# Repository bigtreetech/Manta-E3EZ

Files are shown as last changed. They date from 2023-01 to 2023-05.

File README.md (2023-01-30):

# Manta-E3EZ
## Note
With the Manta E3EZ board, we packed it with so many features and connectivity options that we needed to use M2 standoffs instead of M2.5 beneath the CB1 due to the track density. M2 screws will be included with most boards but if you do not receive M2 screws with your board then the specificatons for the correct screw are: M2x10, 4pcs.

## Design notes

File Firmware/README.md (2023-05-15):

# Writing bootloader for E3EZ
1. Download the [bootloader.bin](./E3EZ_bootloader.bin) file to CB1/CM4.
2. Press and hold the boot button of E3EZ and then click the reset button to make E3EZ goto DFU mode.
3. Run the following command on the Terminal of CB1/CM4 to write the bootloader
    ```
    sudo dfu-util -d ,0483:df11 -R -a 0 -s 0x8000000:leave -D ./E3EZ_bootloader.bin
    ```
    `0483:df11` is the DFU ID of M8P (We can get it by running `lsusb` command)</br>
    `./E3EZ_bootloader.bin` is the Path of bootloader file.

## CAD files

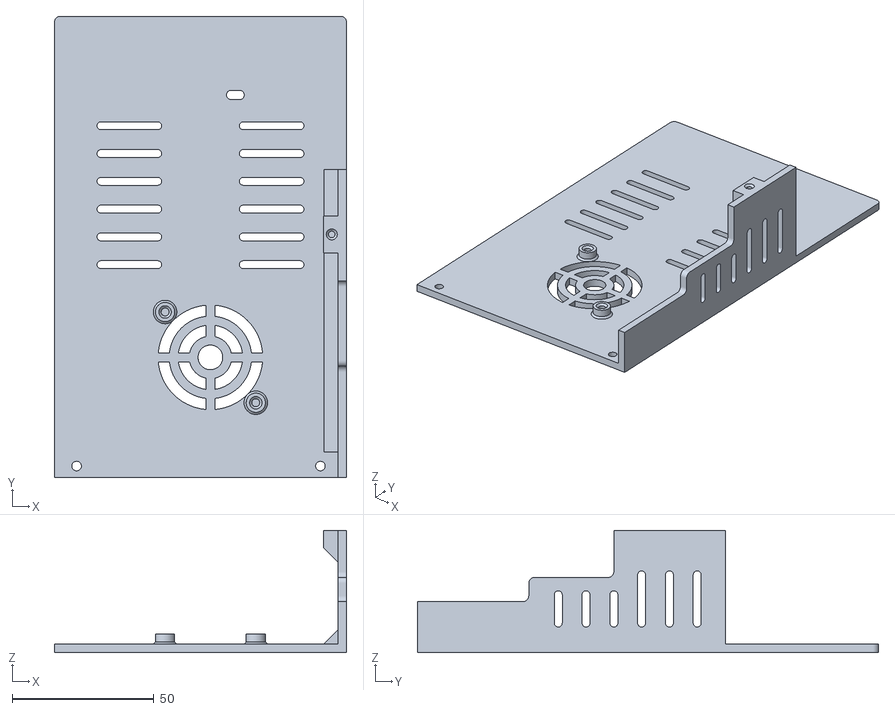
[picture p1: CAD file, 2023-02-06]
Ender3 V2 STL/Back enclosure.stl
103.0 x 162.7 x 43.1

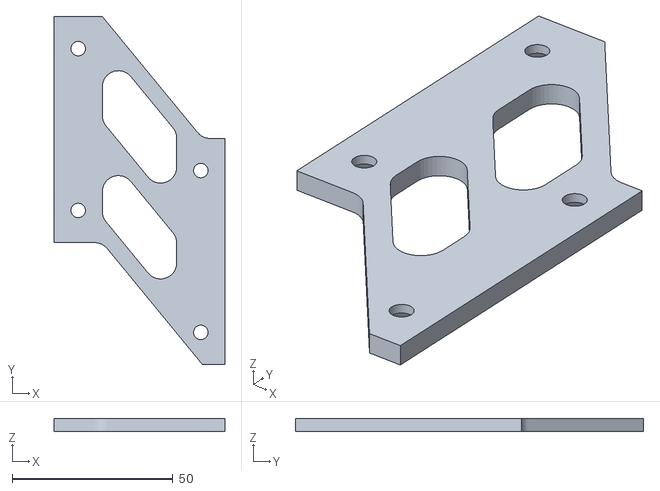
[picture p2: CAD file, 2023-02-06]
Ender5 STL/Ender5.STL
53.1 x 108.2 x 4.00

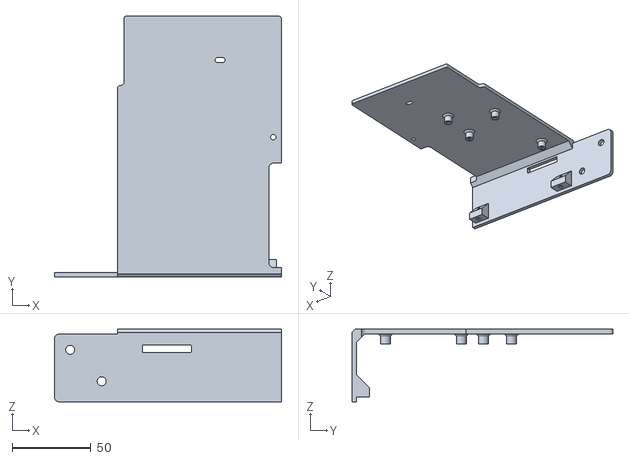
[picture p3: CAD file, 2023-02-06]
Ender3 V2 STL/Front enclosure.stl
144.2 x 165.7 x 46.1

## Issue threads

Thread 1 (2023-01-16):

How to setup the internal CAN interface?

rclarke250, 2023-01-16:
config says CAN bus (on PB12/PB13) and that is not a choice in make menuconfig.  So how does one setup the internal CAN interface with a CB1 mounted on the board?

emersonsc, 2023-01-30:
Looks like there is a pull request but Kevin being Kevin has an issue with something stupid and its being held up.

looxonline, 2023-01-30:
For now, you'll need to use the BTT klipper branch where it is supported until Kev upstreams it. https://github.com/Klipper3d/klipper/pull/5981

JamesH1978, 2023-02-01:
The issue is that the files submitted in the PR https://github.com/Klipper3d/klipper/pull/5981 , contain sections for [tmc2240] module which does not exist in mainline klipper. Until btt submits this modile to add the functionality the PR will probably stay stale.

Thanks
James

mar-cun, 2023-02-03:
Any update/idea on when this might get incorporated? I am trying to upgrade my printer right now with the E3EZ and an EBB42 (not that I can find any specific instructions on how to accomplish that, so I have an email into tech support). So in the interim I ended up copying the two updated files from the pull request (kconfig & fdcan.c) and overwriting them in my klipper folders and I was successful in getting the PB12/PB13 options to show up, but not sure if something else is needed. When trying to query for the can bus ID at the end of the setup I get a device not found. But not sure if that's just something else I'm doing wrong, or if it's a problem with the environment.

rclarke250, 2023-02-08:
The latest Klipper3d update allowed me to get CAN functioning.  A setup guide in the manual would be helpful for those not familiar with using USB to CAN bridge mode.

hauserkristof, 2023-08-04:
Hi @rclarke250 !

Can you help me with enabling the CAN Bus on the device? I'm struggling with it a bit.

Thank you in advance,
Kristóf

rclarke250, 2023-08-05:
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

Sure what do you need help with?

yourbuddydinec, 2023-08-08:
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

I was curious what you chose for the pins on katapult/Canboot. It looks like on the E3EZ it should be the PC12/PB13 but the only choice in Canboot is PD12/PD13

rclarke250, 2023-08-08:
I didn't use Canboot. I just used Klipper make menuconfig...set the STM device to USB bridge mode, and set the pins for can, make and copied to a microsd after changing klipper.bin to firmware.bin and booting the machine.

Deapper, 2023-08-13:
> I didn't use Canboot. I just used Klipper make menuconfig...set the STM device to USB bridge mode, and set the pins for can, make and copied to a microsd after changing klipper.bin to firmware.bin and booting the machine.

Do you use an EBB tool head? I setup the MCU for canbus but could not see the ebb42 I have.

I followed this guide https://www.youtube.com/watch?v=EA-oBfenxAE&t=160s

rclarke250, 2023-08-13:
Yes, I actually have 2 EZ boards, one on an Ender 3 pro with CAN to an
EBB42, and another in an Artist-D pro running 2 EBB42 in Idex with BTT
H2's.

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

Deapper, 2023-08-13:
So do you use the following under make menuconfig?
USB bridge - CANBUS - PB12 PB13?
Both Manta and EBB42 usb to (CAN bus (on PB0/PB1)?

Also what baudrate do you use? 1000000?

And do you have the 120omh pin shorted on both Manta and EBB42?

thanks

rclarke250, 2023-08-14:
The Manta yes, USB-Canbus-PB12,PB13.
The EBB Canbus PB0,PB1
I used Baud rate 500000. Doesn't seem to be an issue.
And yes, 120 Ohm jumper on each.
cable has to be twisted, with High to High, Low to Low. Doesn't need to have a lot of twist,  I also twisted my Power cables with it, and is working okay.

Deapper, 2023-08-15:
Thank you.

Closed 2023-02-09.

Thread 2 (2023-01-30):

How To put board in DFU Mode

emersonsc, 2023-01-30:
the usual reset + boot button method does NOT put the board in DFU mode, making it impossible to update firmware via STM32Programmer

DarKingF0x, 2023-01-30:
Right next to the front USB there is a dip switch that you need to switch to the opposite direction in order to use the DFU mode it's in the manual

looxonline, 2023-01-30:
> Right next to the front USB there is a dip switch that you need to switch to the opposite direction in order to use the DFU mode it's in the manual

The switch next to the micro USB connector is related to the interface that is presented to the micro USB port by the CB1 and will not impact DFU mode on the MCU. One direction offers a direct USB connection which allows downloading firmware onto an embedded eMMC and the other allows a UART connection via a converter IC which allows serial debugging or serial terminal commands.

DarKingF0x, 2023-01-30:
Ssh into board via serial connection, run kiuh, and flash

dogjutsu, 2023-03-05:
I was able to un-brick my Manta E3 EZ firmware from the OS on the CB1 -- this is what I did, not sure if everything being unplugged is necessary:

- Board with CB1 installed (OS already installed on installed SD Card) completely unplugged from everything, USB power jumper applied.
- Hold down BOOT button (middle of the board near the middle stepper driver) while plugging in USB power, release BOOT button once powered.
- SSH into CB1, confirm dfu mode vis 'dmesg | grep -A4 dfu' -- should see something like:

```
[    3.591220] usb 2-1.1: New USB device strings: Mfr=1, Product=2, SerialNumber=3
[    3.598544] usb 2-1.1: Product: DFU in FS Mode
[    3.598552] usb 2-1.1: Manufacturer: STMicroelectronics
[    3.603853] Freeing unused kernel memory: 2176K
[    3.608236] usb 2-1.1: SerialNumber: <REDACTED>
```

- Install 'fwupd' package:  'sudo apt-get update ; sudo apt-get install fwupd'
- Optionally, further confirm DFU mode via 'fwupdmgr get-devices':
```
biqu@klipper:~/klipper$ fwupdmgr get-devices
WARNING: UEFI capsule updates not available or enabled in firmware setup
  See https://github.com/fwupd/fwupd/wiki/PluginFlag:capsules-unsupported for more information.
BQ-H616
│
└─DFU in FS Mode:
      Device ID:          <REDACTED>
      Current version:    2.0
      Vendor:             STMicroelectronics (USB:0x0483)
      GUIDs:              <REDACTED>
                          <REDACTED>
      Device Flags:       • Updatable
                          • Is in bootloader mode
```

- Flash klipper.bin with dfu-util (serial from dmesg above):
```
biqu@klipper:~/klipper$ sudo dfu-util -D ./out/klipper.bin --serial <REDACTED> -a 0 -s 0x8002000:leave -R
dfu-util 0.9

Copyright 2005-2009 Weston Schmidt, Harald Welte and OpenMoko Inc.
Copyright 2010-2016 Tormod Volden and Stefan Schmidt
This program is Free Software and has ABSOLUTELY NO WARRANTY
Please report bugs to http://sourceforge.net/p/dfu-util/tickets/

dfu-util: Invalid DFU suffix signature
dfu-util: A valid DFU suffix will be required in a future dfu-util release!!!
Opening DFU capable USB device...
ID 0483:df11
Run-time device DFU version 011a
Claiming USB DFU Interface...
Setting Alternate Setting #0 ...
Determining device status: state = dfuIDLE, status = 0
dfuIDLE, continuing
DFU mode device DFU version 011a
Device returned transfer size 1024
DfuSe interface name: "Internal Flash   "
Downloading to address = 0x08002000, size = 26664
Download        [=========================] 100%        26664 bytes
Download done.
File downloaded successfully
dfu-util: Error during download get_status
```

- After a few seconds, your `/dev/serial/by-id/usb-Klipper_stm32g0b1xx_XXXXXXX-if00` device should re-appear.  You can also grep for 'Klipper' in dmesg to confirm:  `dmesg | grep -C5 -i klipper`

Hopefully this helps unbrick somebody else unbrick their firmware without resorting to ST-Link (which I couldn't get to work, fwiw).

dogjutsu, 2023-03-05:
Addendum: The above didn't 'stick' after reboot, however I was able, with everything plugged in, to enter DFU mode by holding down the BOOT button while powering on, then this worked and stuck:

make flash FLASH_DEVICE=0483:df11

dogjutsu, 2023-03-05:
Update:  My mistake, that apparently does not survive power cycle either.

looxonline, 2023-03-05:
> Update: My mistake, that apparently does not survive power cycle either.

What do you mean that it does not survive a power cycle? Does the MCU no longer appear to the CB1 over the USB link after a power cycle?

dogjutsu, 2023-03-05:
> > Update: My mistake, that apparently does not survive power cycle either.
>
> What do you mean that it does not survive a power cycle? Does the MCU no longer appear to the CB1 over the USB link after a power cycle?

So immediately post `make flash` after a few seconds the klipper device appears under `/dev/serial/by-id/usb-Klipper_stm32g0b1` and I can start the Klipper service and everything works -- but after rebooting the /dev device doesn't show up and no sign of the device in lsusb / dmesg (unless I boot to DFU mode).

I suspect what's going on is although I flashed the actual Klipper firmware, the bootloader is hosed, so there is nothing to load correctly boot the Klipper firmware.

I'm going to see if there's a way to initiate whatever reset the dfu-util is doing without actually flashing, then I can just make that happen on boot.

looxonline, 2023-03-05:
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

Why don't you just reinstall the bootloader? Install canboot and set it to operate in USB mode.

dogjutsu, 2023-03-05:
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

I've been poking around for a bootloader bin/hex/etc that'll work for the stm32g0b1 ... happen to know where to source one?

looxonline, 2023-03-05:
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

Canboot is the way to go https://github.com/Arksine/CanBoot

dogjutsu, 2023-03-05:
> Canboot is the way to go https://github.com/Arksine/CanBoot

Thanks, I'll see what I CAN do!

dogjutsu, 2023-03-05:
> > Canboot is the way to go https://github.com/Arksine/CanBoot
>
> Thanks, I'll see what I CAN do!

@looxonline thanks a bunch for the tip, I'm good to go now!

For those playing along at home, basically followed the instructions here:
https://github.com/Arksine/CanBoot/issues/61#issuecomment-1405721325

...and then remembered to setup my printer.cfg accordingly:

```
[mcu]
canbus_uuid: <redacted>
```

looxonline, 2023-03-05:
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

Good stuff!

Tina-Builds, 2023-05-08:
@looxonline
Do you know where to find the original bootloader, eg. if someone has installed CanBoot and wants to go back?

killrmodz, 2023-06-25:
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

Followed all of the instructions above, and my firmware seems to flash but doesn't as a powercycle won't allow klipper to come up without putting back in the microsd.  So i'm lost here and am looking for guidance.  Thanks!

Valiance, 2023-08-23:
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

I have to drive with my SD card inserted in the Manta E3 EZ board.

looxonline, 2023-08-23:
> @looxonline Do you know where to find the original bootloader, eg. if someone has installed CanBoot and wants to go back?

Completely missed this but the bootloader is in the files section.

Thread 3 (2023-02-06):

Ender 3 v2 Enclosure Damages SD Card

cmcfalls2, 2023-02-06:
I noticed that the mainboard sd card slot directly aligns with the E3v2 mounting pin location. If I reattach my electronics enclosure cover it is going to tear the SD card slot off the board. Seems like a bit of an oversight. Either move the SD card location slightly or push it further underneath the board since it can't be accessed with the board installed anyway. Is there an update/fix coming for this? I don't want to install it in my other v2's if there is a revision coming.

looxonline, 2023-02-14:
See enclosure STLs that have been uploaded for the E3pro/V2 and 5.

blandry80, 2023-02-16:
> See enclosure STLs that have been uploaded for the E3pro/V2 and 5.

Can someone resubmit the file for the front enclosure, all I am getting is the raw code? Thank you in advance.

looxonline, 2023-02-17:
> > See enclosure STLs that have been uploaded for the E3pro/V2 and 5.
>
> Can someone resubmit the file for the front enclosure, all I am getting is the raw code? Thank you in advance.

You may need to right click on the download link and say "Save file As"

markewert, 2023-04-03:
Even with 'Save file As' the file is corrupt. Since without this the Manta E3EZ cannot be used, I am going to have to return it which is annoying.

looxonline, 2023-04-03:
> Even with 'Save file As' the file is corrupt. Since without this the Manta E3EZ cannot be used, I am going to have to return it which is annoying.

It's really just this simple. I just tried it and it works perfectly. https://www.gitkraken.com/learn/git/github-download#how-to-download-a-file-from-github

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

markewert, 2023-04-03:
Partial thanks to @looxonline . I download files off GitHub all the time but there's a trick to this one and Luke's "simple" instructions are only partially accurate. After you click the filename from the list there will not be a 'Raw' button. The 'Download' button next to the file also does not work normally (this is what should be fixed). Instead, right-click on the Download button and choose 'Save Link As'. The file that downloads will not be corrupt.

looxonline, 2023-04-03:
> Partial thanks to @looxonline . I download files off GitHub all the time but there's a trick to this one and Luke's "simple" instructions are only partially accurate. After you click the filename from the list there will not be a 'Raw' button. The 'Download' button next to the file also does not work normally (this is what should be fixed). Instead, right-click on the Download button and choose 'Save Link As'. The file that downloads will not be corrupt.

I grabbed a screenshot of the "Raw" button as I was making that response. It's exactly what was on my screen. Maybe your browser does something different with the file. In any case, in my earlier response I also mentioned the "download link" which would apply to your "download" button.

Dids, 2023-06-24:
The download issues are due to Git LFS. Downloading the zip archive of the entire repository should include all the files, but alternatively you can also install both git and git-lfs and clone the repository.

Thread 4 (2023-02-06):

Ender 3 Pro support

emersonsc, 2023-02-06:
Will there ever be support for the Ender 3 Pro? The board does not fit in the Stock "upside down" electronics box unless you have no plans on using the cat5 or usb connections.

looxonline, 2023-02-14:
It is exactly the same as the E3V2.

DarKingF0x, 2023-02-27:
Same on regular E3. Will have no access to the HDMI, USB or the network cable. I absolutely love this board just wish I could fit it in there and be able to use it

looxonline, 2023-02-27:
> Same on regular E3. Will have no access to the HDMI, USB or the network cable. I absolutely love this board just wish I could fit it in there and be able to use it

This would likely get you sorted for HDMI on the regular Ender 3: https://www.adafruit.com/product/3557

emersonsc, 2023-02-27:
> Same on regular E3. Will have no access to the HDMI, USB or the network cable. I absolutely love this board just wish I could fit it in there and be able to use it

Not sure about that. Once I used the files Luke pointed out, I have access to the network cable on me 3Pro. I don't use the HDMI so I can't say because I didn't pay attention.

> This would likely get you sorted for HDMI on the regular Ender 3: https://www.adafruit.com/product/3557

That's nifty, thanks!

I'm going to mark this closed as Luke pointed out the files work for the 3 Pro as well

docdawning, 2023-04-18:
I'd like BTT to also offer an all metal chassis option to fit this board on an E3 chassis.

Closed 2023-02-27.

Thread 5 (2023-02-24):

Manta E3EZ - CM4 - Camera/DSI ports not working

Will-wastelander, 2023-02-24:
Unable to get DSI screen or rPi cam to work on this board. I have copied the dt-blob.bin file to /boot as stated in documentation. What other steps are required to get these items working ? Screen is BTT PiTFT50 v2.0, and Camera is rPi NoIR camera. Camera worked on rPi 4 4GB before switching to Manta E3EZ mainboard. I have already replaced the cables with brand new ones, and confirmed that they are connected correctly.

`
pi@mainsailos:~ $ vcgencmd get_camera
supported=0 detected=0, libcamera interfaces=0
`

Will-wastelander, 2023-02-26:
Got display working, but camera is still not working.

Will-wastelander, 2023-02-27:
This is my second board that is doing the same thing.

DarKingF0x, 2023-02-27:
Using a CM4 or CB1?

DarKingF0x, 2023-02-27:
Cm4 should use hdmi, for this particular board the CB1 uses the SPI DSi, and CM4 hdmi

Will-wastelander, 2023-02-27:
I have DSI display working w/ CM4, I need to get rPi camera working now.

looxonline, 2023-03-06:
Just copying a pic of your comment on Discord over to here for reference:

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

Will-wastelander, 2023-03-06:
Determined that a CSI  "A type" cable is required in order for the camera to work, as the pins are in fact incorrect on the Manta E3EZ. The below 2 items are what I had to use in order for a standard 2 foot CSI cable to work. The pins are mirrored from what the standard CSI pins are.

https://www.amazon.com/uxcell-Flexible-Cable-Ribbon-Player/dp/B07RVD2MZV/
https://www.amazon.com/gp/product/B07RWF4QCY/

karrui, 2023-03-22:
If you do not want to buy a new type A FFC, you could also peel away the plastic backing of one end and fold the now soft connectors upwards to form a pseudo type A FFC from a type B.

looxonline, 2023-03-23:
> Determined that a CSI "A type" cable is required in order for the camera to work, as the pins are in fact incorrect on the Manta E3EZ. The below 2 items are what I had to use in order for a standard 2 foot CSI cable to work. The pins are mirrored from what the standard CSI pins are.
>
> https://www.amazon.com/uxcell-Flexible-Cable-Ribbon-Player/dp/B07RVD2MZV/ https://www.amazon.com/gp/product/B07RWF4QCY/

As we discussed on Discord, I have confirmed that the pins on the Manta E3EZ are not inverted and there are simply different connectors used between it and the Pi4b adapter which is why the numbering looks different. I can also prove this based on not my evidence, but the evidence that you have provided. See below.

You state that you fixed this issue by purchasing a type A cable and an extender and using them in combination with a standard, 2 foot CSI cable. Let's put this statement to the test and see if it results in an overall type A or type B cable.

Some important things to note are:
- The extender only has contacts on one side.
- The extender is straight through.

Drawing the cable type using ASCII art below reveals something interesting:

TOP ---------2ft TypeB------------- BOTTOM (EXT IN) -- (EXT OUT) BOTTOM -----------TypeA--------- BOTTOM

We note that the combination you have mentioned actually results in an overall type B and *not* a type A. Since you state that this works, this proves that the Manta E3EZ pins are correct.

I would have to assume that either you were originally using the extender with two type B cables or you were originally using a single type A. Either way, it is not cool to mislead others into thinking that they need to purchase a type A cable for the board to work. If this was done by mistake, then that is understandable because it is easy to get lost in the details of which side of the connector should go where and what cable is what type. Nevertheless, I want other reading this thread to please take note of this comment so that they do not purchase a type A cable only to find it not working.

Additional evidence of the extender flipping the type is found in the amazon reviews for it:

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

Will-wastelander, 2023-04-15:
So after 4 boards, I was able to get this working with my original setup.

Gabbajoe, 2023-10-18:
> If you do not want to buy a new type A FFC, you could also peel away the plastic backing of one end and fold the now soft connectors upwards to form a pseudo type A FFC from a type B.

Hi this hint made for me on a Manta M5P the raspberry Pi cam v3 working! If I use the Type B cable the CM4 module on my Manta M5P gose away. this means my shells closes and ping to the host is no longer possible also the the activity LED was just dim flickering and the CM4 module never boots. So I the cam connector on the Manta M5P is wrong.

jevermeister, 2025-01-10:
The pins are not reversed. It's just that the CSI connector needs to have the cable the other way around. Use a regular cable (Type B / reverse, so the blue ribbon is on a different side on each end) just as the ones which are shipped with e.g. the Raspberry Camera Pi 3 and insert them according to this picture. If you buy a Type A or peel of the plastic of your type B and wrap it around, you will shorten your 3.3V rail and the Pi won't boot up. Luckily it did not damage anything for me.

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

Closed 2023-04-15.

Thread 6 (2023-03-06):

Manta EZ 3 and Sprite Extruder

jeremi2305, 2023-03-06:
I for the life of me cannot figure out the issue I am having. I am attempting to upgrade my ender 3 with a Manta EZ3 and the board resets any time the fan and heater are activated at the same time. I can use them independently. I am aware the sprite shares the 24v rail on the breakout board. Seeing that this is an upgrade for the ender 3 I would anticipate this to be taken into account given that on the original creality board the hotend and fans share a 24v rail as well, but reading the schematics of the board they are all separate.

KrisWragg, 2023-03-12:
@jeremi2305 have you tried switching pos+neg of the fan wires? Might be tricky with the JST connector, but worth double checking.

I recall having a similar issue with my Creality 4.2.2 board when I first installed the Sprite Pro Extruder as I had got them mixed up, I think it was the opposite to stock and like usual I didn't read instructions.

Also just double check your HE0 polarity is correct, on the board and schematic it is opposite to the DC IN and HB so HE0 positive is next to DC IN positive.

Personally I'm stuck at a different point as my E3EZ is not being picked up as a USB device on my RPI 4B after installing klipper firmware on the E3EZ :(

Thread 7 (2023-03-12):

Manta E3 EZ with CB1 Klipper

Fieroman911, 2023-03-12:
My board at start up is giving 24v to the heater (HE0) the wires are in the correct slot +/-. could this be an issue where the board is sending power to test the thermistor and I have to switch the wires on the TH0?

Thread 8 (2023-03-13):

Manta E3EZ with rp3 connection

bmorgan99, 2023-03-13:
I get no communication when trying to connect via raspberry pi3b w/USB cable.

firmware uploads,  3V3 is green, firmware.bin renamed
tried 3 cables, all USB ports
removed, reinstalled klipper (kiauh) on pi
no unique by-id serial device is created
normal serial devices don't work, i.e. serial1, ttyAMA0

menuconfig:
```
STM32G0B1
8KiB bootloader
8 MHz crystal
USB (on PA11/PA12)
```
systemctl status klipper.service
```
 klipper.service - Klipper 3D Printer Firmware SV1
     Loaded: loaded (/etc/systemd/system/klipper.service; enabled; vendor preset: enabled)
     Active: active (running) since Sat 2023-03-11 06:36:18 CST; 2h 4min ago
       Docs: https://www.klipper3d.org/
   Main PID: 814 (python)
      Tasks: 2 (limit: 1472)
        CPU: 36.829s
     CGroup: /system.slice/klipper.service
             └─814 /home/pi/klippy-env/bin/python /home/pi/klipper/klippy/klippy.py /home/pi/printer_data/config/printer.cfg -I /home/pi/printer_data>
```

KrisWragg, 2023-03-13:
As discussed on biqu community I have the same issue :(

Things I have tried:

1. Power board via USB instead of 24v DC by adding jumper to VUSB
2. Try all 4 USB ports on Raspberry Pi 4B
3. Try 3x USB cables
4. Update klipper to latest (was about a month behind before) and recompile firmware
5. Update Raspberry Pi OS to latest
6. Run command 'dmesg' - nothing new found
7. Run command 'lsusb' - nothing new found

I am wondering if maybe the connection option is actually wrong and it should be something else? Or the CPU is actually a slightly different model?

It's clearly accepting a firmware so the board isn't dead but just not communicating via USB.

KrisWragg, 2023-03-13:
Looking at the schematic I think one thing I might try next (tomorrow?) will be to try and reuse the TFT connections rx/tx as UART.
https://github.com/bigtreetech/Manta-E3EZ/blob/master/Hardware/BIGTREETECH%20Manta%20E3EZ%20V1.0-SCH.pdf

Pins 3&4 for TFT can be used I think which would correspond to **Serial (on USART3 PD9/PD8))** in the make menuconfig settings.

Then can change klipper config to

```
[mcu]
serial: /dev/ttyAMA0
baud: 250000
restart_method: command

```

On Raspberry Pi I think you need to disable bluetooth by adding **dtoverlay=disable-bt** to /boot/config.txt

Then ensure that serial console is disabled:

```
sudo raspi-config
Select option 5 - Interfacing Options.
Select option P6 - Serial.
Select No - a serial console should not be available.
Select Yes - The serial hardware should be enabled.
```

KrisWragg, 2023-03-13:
So to clarify refer to:
https://github.com/bigtreetech/Manta-E3EZ/blob/master/Hardware/BIGTREETECH%20Manta%20E3EZ%20V1.0-PIN.png
https://cdn.sparkfun.com/assets/learn_tutorials/1/5/9/5/GPIO.png

TFT PD8 (TX) -> RPI GPIO 15 (RXD) aka Pin 10
TFT PD9 (RX) -> RPI GPIO 14 (TXD) aka Pin 8

KrisWragg, 2023-03-14:
Just a note, unless I am being dumb this isn't working either. Firstly it wouldn't compile klipper firmware with **Serial (on USART3 PD9/PD8))** selected.

I fixed this by editing klipper/src/stm32/stm32f0_serial.c and tweaked an existing if/def to properly define USART3_IRQn

```
  #if CONFIG_MACH_STM32G0B1
    #define USART2_IRQn USART2_LPUART2_IRQn
    #define USART3_IRQn USART3_4_5_6_LPUART1_IRQn
  #endif
```

This compiled fine and installed on the board, but trying to use those pins is not getting me connected to it either. So I'm starting to wonder if this board is just duff or it's totally misdescribed either because it only functions with a CM4/CB1 or the settings are wildly different to those documented i.e. different chip???

bmorgan99, 2023-03-14:
If it was only ever intended for CB1/CM4 use, seems like they would want to clear that up as soon as possible.  That's a big oversight in my mind, and I looked hard for that before pulling the trigger.

Sonnenwerk, 2023-03-22:
I have the same issue..I got it as a replacement for my SKR Mini. But the board is not found on the usb port (using the same setup port/cable as before). Nothing i did (including steps above) helped !

KrisWragg, 2023-03-22:
I finally had a response to my ticket with them, it was as I suspected...

> The reason is this: On Manta series motherboards, the USB of the MCU is directly connected to the socket of the core board, and there is no connection to the type-c port. If you use a raspberry pie, it cannot be connected to the raspberry pie through a typeC cable and then communicate using USB, unless you use CB1 or CM4.
>Sorry for any inconvenience caused.
>BIQU

bmorgan99, 2023-03-22:
@KrisWragg
Since it was a personal reply and neither the product page or this github was corrected, they must be happy with extra (unfortunate for us) sales.

KrisWragg, 2023-03-22:
Yes what they are saying is using a CB1/CM4 is mandatory not optional which is not as advertised. Will escalate my PayPal refund I think.

bmorgan99, 2023-03-22:
I will accept a CB1 as recompense :)

looxonline, 2023-05-07:
> Yes what they are saying is using a CB1/CM4 is mandatory not optional which is not as advertised. Will escalate my PayPal refund I think.

It is optional if you choose to run Marlin. This is why it is advertised as such.

bmorgan99, 2023-05-08:
It won't work with Octoprint if the USB port is unresponsive.  A very popular app.

bmorgan99, 2023-05-08:
Octoprint won't connect without a functional USB port.  Critical for many.

looxonline, 2023-05-08:
> Octoprint won't connect without a functional USB port. Critical for many.

Octoprint can connect via UART when using a USB to UART converter. The board is designed to host the SBC connection locally. If you want a board that hosts it externally then I would recommend the SKR Mini E3 or the SKR 3 EZ.

bmorgan99, 2023-05-08:
I would have had I known.  I had planned to stay with Marlin (printing noob), wait on CM4s to come down in price and go to Klipper.  That detail would have been nice to have.

looxonline, 2023-05-09:
>

Why not just use the CB1 instead of wait for the CM4 to go down? The CB1 is a little more powerful than the Pi3B+ and more than enough to do all that klipper needs.

Jo0, 2023-05-10:
Product page mentions the use of a TPS5450-5A to help with powering external RPis. So in theory we should just be able to take our existing klipper setups, plug our Pi to the Manta, and update the printer.cfg to accommodate the new board.

Plenty of us have existing setups and just want to upgrade boards for any number of reasons. (ie. Wanting to move away from my modified 4.2.7 board for dual independent Z, and utilize a board that has the feature built in.)

Sure, going to CB1 or CM4 directly is an option, but what if we want to save some costs upfront when the existing setup isn't broken or detrimental in any way.

looxonline, 2023-05-10:
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

Yes, an external pi will work if you use it via SPI or UART which is not difficult to do and does not need any special adapters. You just wire the pi directly to the board using the UART lines. The product page is very clear, in many places, that this is designed primarily for use with the CB1 or CM4. The product description is the leader to the rest of the page and states this clearly.

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

If you still want to use it with an external pi then I would suggest going the UART route as it is very simple. Simply wire TX on the pi to RX on the board and vice versa. Ensure ground is hooked up and that you have configured the firmware to comm over the correct UART and at the correct baud and it will work without an issue.

rakosi2, 2024-03-09:
I have created a PR in Klipper that will allow the use of UART on the TFT pins.
In the `make menuconfig` select Communication interface to `Serial (on USART3 PD9/PD8)`
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

fleXXo22, 2024-12-25:
Has tehre been any news on this? I have been trying to follow everything done here, but i cant get the connection to the MCU.
Please see the following Screenshots:
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
I also edited the /boot/firmware/config.txt and deactivated bluetooth.

rakosi2, 2024-12-26:
PD9/PD8 is on the TFT connector, please take a look at the pinout
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

fleXXo22, 2024-12-26:
As far as i can see this is connected correctly.
I have it connected as follows:
Black/Gray Cable: Pin6 (GND) - TFT GND
Yellow/White Cable: Pin 8 (GPIO 14 TXD) - TFT PD9
Red/Purple Cable: Pin 10 (GPIO 15 RXD) - TFT PD8

Please see the attached Photos. Am I missing something here?
Thank you for your help.
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

rakosi2, 2024-12-26:
I used a FTDI cable cause I used a PC and not a pi. I would make sure that the baud rate is the same on both sides. For a RPi, you change it in cmdline.txt so change 115200 to 250000

fleXXo22, 2024-12-26:
My cmdline.txt says the following: `console=tty1 root=PARTUUID=a6f4af0e-02 rootfstype=ext4 fsck.repair=yes rootwait cfg80211.ieee80211_regdom=DE
`
Where do i have to add that?

rakosi2, 2024-12-26:
I would add:
console=ttyAMA0,250000
May have to reenable that uart service, not sure as I don't use a raspberry pi

fleXXo22, 2024-12-26:
I have added that and reenabled the uart service. Cant get a connection still. Do you have any other ideas I can try?

mikemerryguy, 2025-01-28:
> I have created a PR in Klipper that will allow the use of UART on the TFT pins. In the `make menuconfig` select Communication interface to `Serial (on USART3 PD9/PD8)` 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

you are my HERO!!!
I just got two of these boards, and assumed the same as everyone else that I would be able to use a USB cable!!

I am running a repurposed Ubiquti Application server and thought the CM4 was nice, but really just liked the idea of this board and it was on a pretty good deal!

Then I get to the dreaded "cant mind MCU" no matter what, stumbled across this, ordered a couple FDTI cables off amazon, and BOOM reflashed with the usart3, and I now and controlling the beast from my liunx install!!!!

have yet to flash the other one, soon I will, have two printers getting these boards and have to print a plate to get it to sit where I want in the Sunlu S8 case and not short out the pins on the underside!!!

the other is a standard ender 3 so it will be easier but I only want to have one apart at a time, my bdsensors came today too so I am pretty excited,  The S8 might need some new steppers as they got wet and have some rust inside now haha

things been sitting for YEARS

anyway, thanks again man!

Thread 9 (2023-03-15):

Manta E3EZ+CB1+EBB36 v1.2

alexandrugai, 2023-03-15:
hi there...i need some help. yesterday arrived the ebb36 v1.2 and i'm trying to connect it to manta e3ez over can. manta flashed with klipper and selected "usb to can bus bridge (usb on PA11/PA12 and canbus on PB8/PB9)" and here begins the problem... when flashed this way, CB1 doesn't recognize manta anymore over "usb serial" connection. can0 network appears, but just the manta, not the ebb36. to mention that when i try to flash the ebb36 with stmcube i get an error "download failed" or something like this but when i flash it with canboot, flashes ok. in the manta manual i didn't found nothing about can bus. after first attempt to flash the ebb, it remains with one led full lit and the other one barely visible.

hauserkristof, 2023-08-04:
Hi @alexandrugai !

Did you manage to set up the EBB36 with the E3EZ?

If yes, than how? Can you help me with it please?

Thanks

Closed 2023-03-28.

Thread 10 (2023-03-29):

the guide doesnt show all the pins!!

MasterSe7en777, 2023-03-29:
im trying to add a dual Z stepper and i cant find the stepper pin so i can put it in the config, none of the stepper are labeled on the pinout please help

Valiance, 2023-04-19:
I am right behind you on this, I am trying to add my Z2, and am not finding any references that work for the Pinout.
Where did you find your pinout?
I know some of the pins would be identical for Z & Z2, I was planning to have independent steppers so I could program the dual Z auto-leveling feature.
I am stuck.   (Does not help I have never used Klipper before.)

DarKingF0x, 2023-04-20:
The dual z axis for this board is NOT independent. You should have been more clear on that. You can have two stuffer motors plug into those two spots but they're going to run at the same time at the same space they are not independent.
If you want dual independency you're going to have to convert your second extruder Port into a Z1 and label your 1st zport as Z0.
You will have to update your printer config.

MasterSe7en777, 2023-04-20:
Yeah sorry I didn't post my update, the z1 and z2 ports are tied together, if you look at the board traces they are both connected so basically only 1 driver controls them all I did was bump the current up to I believe 0.80 amps and it's totally fine driving both steppers

DarKingF0x, 2023-04-20:
What z motors are you using? Creality?

Tw0pay, 2023-09-08:
this is part of my config with Z1 taking place of E1
`#   STEPERS Z  #

[stepper_z]
step_pin: PD2
dir_pin: !PD4
enable_pin: !PD3
microsteps: 16
rotation_distance: 8
endstop_pin: probe:z_virtual_endstop
#position_endstop: 0
position_max: 250
position_min:-15
homing_speed: 25
second_homing_speed: 1
homing_retract_dist: 2
homing_retract_speed: 10
homing_retract_speed: 5

[stepper_z1]
step_pin: PB7
dir_pin: !PB6
enable_pin: !PB4
microsteps: 16
rotation_distance: 8`

Valiance, 2023-09-09:
I resolved my Z & Z1 issues.   What I would up doing: I used stepper_z as default, then used E1 (Not E0) to set up Stepper_z1 for the second separate z rod control.  I used my pinouts for E1, and changed my printer.cfg file similar to what Tw0pay has listed above.  I also setup z_tilt, as per Klipper.3D's configuration https://www.klipper3d.org/Config_Reference.html Now, my Z rods will run separately, and tune themselves level.

daveneeley, 2024-08-17:
Just putting this here for the search engines...On Marlin for independent z-axis, change `Marlin/src/pins/stm32g0/pins_BTT_MANTA_E3_EZ_V1_0.h`

```
// Use the same Pins as Z2 (can only have one or the other configured)
// #define E1_STEP_PIN                         PB7
// #define E1_DIR_PIN                          PB6
// #define E1_ENABLE_PIN                       PB4
//#ifndef E1_CS_PIN
//  #define E1_CS_PIN                         PB5
//#endif

// Use the same Pins as E1 (can only have one or the other configured)
// There is a Z2_Motor connector on the board, but this is not for independent control
// It works the same way as the mini skr e3v3 (it just powers both motors from one driver)
// https://github.com/bigtreetech/Manta-E3EZ/issues/10
#define Z2_STEP_PIN                         PB7
#define Z2_DIR_PIN                          PB6
#define Z2_ENABLE_PIN                       PB4
#ifndef Z2_CS_PIN
  #define Z2_CS_PIN                         PB5
#endif
```

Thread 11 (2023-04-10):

HDMI Port, what kind is it?

Valiance, 2023-04-10:
Thank you for your time and energy in bringing us this card.  I believe it has great potential for greatness within the Ender 3 Community.  I am very hopeful to get this card up and working.

There are a few HDMI port options of that approximate size.  Even just knowing what it really was - would save time & money for its users.

I am not finding any documentation that properly identifies the correct type of port on this board.
This includes the pinout pic, the Cable management pic, and the User Manual - with said pics included.

What makes this a card killer; is that a user needs to access the card via the HDMI port in order to properly set it up, even for headless mode.

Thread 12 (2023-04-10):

The CB1/CM4 module mounting Brass inserts in the mainboard size?

Valiance, 2023-04-10:
Thank you for bringing us this new board.  It is looking like you have outdone yourselves in its creation.

The Brass inserts are reported to be M2 and are too small even for the included screws.  I tried to get an M1.5x5mm for testing purposes to fit the threads, for thread ID, and that was not close to the correct size either.   What are the real thread sizes for these brass mainboard inserts for securing the Compute module?

Valiance, 2023-04-16:
Granted I still do not have the actual thread pitch and thread size, but...
It was pointed out to me, that the (4) M2*10mm are not the intended screws.
The correct screws are located inside the white back, loosely mixed with the electronic connector bits.   All four of them.
So, hopefully, this can be documented for the other poor saps who go thru this experience, and find their screws so they are not as loose as mine were.

Closed 2023-04-16.

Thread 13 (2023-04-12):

Poor canbus labelling

Tina-Builds, 2023-04-12:
The 'new' manual, pinout and schematics lack the information of how to connect to your canbus devices:

1. The manual (vers. 4.4.2023) now has updated labels for the "FACAN" connectors, but NO info of which one to use AND NO info where the 120 Ohm resistor is!
2. The pinout .png has now "FDCAN", BUT are both connectors with CAN_H and CAN_L and are connected CAN_H to TX PB13 and CAN_L to RX PB12 or is the right connector CAN_H and CAN_L and the left TX and RX???
3. The schematics .pdf shows for "FDCAN": 3 pinouts, one jumper JP7 and two connectors P16 and P17 labelled with "CAN_P" and "CAN_N"  . P17 has 2 red symbols beside it.

I guess the termination resistor "JP7" is the "120R" jumper direct below the "PWRDET" and left of "MFAN".

Please clarify:
Which is P16 and which is P17!
How to use P16 and P17 together, eg. if you have a Multi Material Unit pcb with CAN and a EBB42. Do set the terminal resistor here or only on the can devices (daisy chain rule, only 1st and last can device are to be terminated!). To extend that scenario: say this is an IDEX system with MMU and has can pcbs for the MMU(other company), the 2. x-axis(EBB36) and 2 for the tool heads(EBB42). If I GUESS right it could be connected: can MMU board (120R) ---- P16 of E3EZ (NO 120R) , P17 of E3EZ (NO 120R) --- EBB36 (NO 120R) -- EBB42 (NO 120R) - EBB42 (120R). ---- = longest cable ; - = shortest cable.

bigtreetech, 2023-04-20:
> I guess the termination resistor "JP7" is the "120R" jumper direct below the "PWRDET" and left of "MFAN".

* Yeah, you are right. https://github.com/bigtreetech/Manta-E3EZ/commit/fbffdc063621e876209fdfdf741b6aa4b38083e4

* P16 and P17 are completely connected in parallel, so their functions are exactly the same. Let me explain why we put two identical seats. Previously, a customer wanted to connect two EBBs for his IDEX printer, he needed to press the CANbus signal lines of both EBBs into the same seat. Therefore, it is recommended that we place two seats as space allows, so that non-standard pressing signal lines are not required. So for you, you can use any seat, whether it's P16 or P17

Closed 2023-04-20.

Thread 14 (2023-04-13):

Camera Not Working

Wmelonhead, 2023-04-13:
I just setup my Manta E3 EZ with a CB1.  Everything looks to be normal, but my camera will not work.  The screen is white in Mainsail.  In my crowsnest log, it says, "error no usable devices found. stopping crowsnest."  This camera worked on my SKR mini E3 V3.  When I plug in the camera into the usb port, a red light comes on the camera for a moment and then goes out.  Do I need to activate the port for my camera?  Do I need to add another file?  Or do I need to connect to the DSI or SPI port?  I read that those don't work with the CB1.  Is that true?  Thanks for the help.

Wmelonhead, 2023-04-14:
Fixed.  I restarted the printer a couple of times and now the camera works.  Now I can get on with seeing what I can do with this board.

Closed 2023-04-14.

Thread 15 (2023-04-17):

Where is Marlin???

Tina-Builds, 2023-04-17:
You have this:
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
Where is the Marlin image???
How to I flash Marlin???

thisiskeithb, 2023-04-17:
The Manta E3 EZ (and entire Manta Series) was added to Marlin on February 7, so pull down the latest `bugfix-2.1.x` until `2.1.3` is tagged and released to use this board under Marlin.

You’ll define it as `BOARD_BTT_MANTA_E3_EZ_V1_0` in `Configuration.h`.

example:

```cpp

// Choose the name from boards.h that matches your setup
#ifndef MOTHERBOARD
  #define MOTHERBOARD BOARD_BTT_MANTA_E3_EZ_V1_0
#endif
```

Tina-Builds, 2023-04-18:
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

Oh no... I just need Marlin to see if the E3EZ then boots into DFU mode. in order to install CanBoot.. Just bad of BTT/Biqu to advertise "Marlin" runs  it and not to have an precompiled file here ...

docdawning, 2023-04-18:
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

@thisiskeithb thanks for the comment! So, just confirming if we place a Marlin firmware.bin built for this board on an SD card and boot with it, the board will automatically flash the Marlin firmware to the board? I'm planning on this board with Marlin without Klipper, at first. I have no CB1 or CM4.

Valiance, 2023-04-20:
Thank you for this thread.
I am seeking the Marlin info found for the Manta E3 EZ as well.   Glad to hear it has been added to Marlin on Feb 07.
I am struggling as to which files to get.

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

I did Download bugfix-2.1.x, both Marlin, and the Config folder.   I am not finding the board listed under the ...Config>Examples>Creality>Ender 3 folder anywhere.  I looked under several printers, but am not finding any reference to the board.  Here  is a pic of the Contents of the Ender 3 folder to explain better.

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

There are two E3 boards, but neither of them have the filename you mentioned: BOARD_BTT_MANTA_E3_EZ_V1_0

I know I am being smooth-Brained here, apologies.

thisiskeithb, 2023-04-21:
> There are two E3 boards, but neither of them have the filename you mentioned: BOARD_BTT_MANTA_E3_EZ_V1_0

`BOARD_BTT_MANTA_E3_EZ_V1_0` is the board name you'll use within Marlin.

There isn't a premade config for this board, so you'll have to build one out for now.

Valiance, 2023-04-22:
Thank you.   I did not know there was not a premade config.
I would have been barking up that tree for far too long.
I did not know one could even make their own premade configuration.
Now I guess it is a matter of locating instructions on how to do such a
thing.
Since there really is no Marlin version for this board, I am forced back
into Klipper again.
I am likely to not be the one who does the task of creating a Marlin config
for the board.
The main reason I am after a Marlin config is to gain true Pinouts for the
board.
The information given seems to be insufficient for each pin call out for
the whole board.

Regardless, thank you kind sir for the information.

On Fri, Apr 21, 2023 at 7:33 PM Keith Bennett ***@***.***>
wrote:

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

thisiskeithb, 2023-04-22:
> I did not know one could even make their own premade configuration.

You can use the SKR Mini E3 V3 config as a starting point. Just update the `MOTHERBOARD` define and go from there. I have a test config, so I’ll try to get it cleaned up and submitted soon.

> The main reason I am after a Marlin config is to gain true Pinouts for the board. The information given seems to be insufficient for each pin call out for the whole board. Regardless, thank you kind sir for the information.

I built the pins file in Marlin from BTT’s pinout & schematics, but that’s also available for review: https://github.com/MarlinFirmware/Marlin/blob/bugfix-2.1.x/Marlin/src/pins/stm32g0/pins_BTT_MANTA_E3_EZ_V1_0.h

Valiance, 2023-04-22:
Awesome, thanks!

On Sat, Apr 22, 2023 at 12:42 AM Keith Bennett ***@***.***>
wrote:

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

thisiskeithb, 2023-04-24:
Here's the PR to add a Manta E3 EZ Ender-3 config to Marlin:
- https://github.com/MarlinFirmware/Configurations/pull/926

Kuzja27, 2023-05-17:
Has anyone installed Marlin on this board?  Technical support unequivocally answers me that this board is only for Klipper and, accordingly, it will not work without CB1 (or equivalent).  At the same time, this board appeared in the Marlin files.  I want to buy this board, but start working with Marlin and then move to Klipper.

Valiance, 2023-05-17:
No, I haven't.

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

Kuzja27, 2023-05-17:
Have you tried or installed Klipper directly? @Valiance

Valiance, 2023-05-17:
Yes, I did.
"Reality is the Ultimate Role-playing game." -- Victor A. Waters '88

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

Kuzja27, 2023-05-17:
@Valiance Too bad you couldn't install Marlin.  I really liked this board with the prospect of future upgrades to my printer.  I'll have to buy another board. I just don’t understand why add this board to the Marlin “Board.h” file if it is not installed there?

Valiance, 2023-05-17:
I agree with you.
I have had a ton of problems with this board

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

thisiskeithb, 2023-10-11:
> Has anyone installed Marlin on this board? Technical support unequivocally answers me that this board is only for Klipper and, accordingly, it will not work without CB1 (or equivalent). At the same time, this board appeared in the Marlin files. I want to buy this board, but start working with Marlin and then move to Klipper.

@Kuzja27: Support must be working from old info. Manta boards will run Marlin without a CB1/CM4 with the only caveat being that you can't connect to the board externally via USB since the USB ports are connected to the CB1/CM4 and not the MCU.

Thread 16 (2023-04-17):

How to boot in DFU mode

Tina-Builds, 2023-04-17:
Please issue a step by step instruction to boot the E3EZ into DFU mode.
I tried all possible combinations:

1. with CB-1 eMMC 16G installed (OS on eMMC installed), boot button pressed, connected to another PI or to PC with µUSB socket, boot button released: only a CH340 USB to SERIAL is found
2. with a CB-1 1G no µSD card inserted, boot button pressed, then connected to PC, release boot button: same CH340... found
3. without CB-1 (Klipper still installed),  boot button pressed, connected to another PI or to PC with µUSB socket, boot button released: only a CH340 USB to SERIAL is found.

How can I start the E3EZ in DFU mode???

bigtreetech, 2023-04-20:
The Type-C port of E3EZ is used to communicate with CB1, There are two functions, OTG/UART:
* OTG: Set the switch according to the eMMC section of User Manual to make the CB1/CM4 eMMC version enter the boot mode, and then write the OS image by Type-C
* UART: Use UART communication with CB1/CM4  by CH340 for debugging functions.

Do you want to put the MCU STM32G0B1 on the E3EZ board into DFU mode to write the bootloader?
If that's the case, Type-C does not have this function, Because the MCU's USB is directly connected to CB1/CM4 through the BTB socket.  We can write firmware to the MCU through CB1/CM4. The steps are as follows:
* Press and hold the boot button of M8P and then click the reset button to make M8P goto DFU mode.
* Run the following command on the Terminal of CB1/CM4 to write the bootloader
    ```
    sudo dfu-util -d ,0483:df11 -R -a 0 -s 0x8000000:leave -D ./bootloader.bin
    ```
    `0483:df11` is the DFU ID of E3EZ (We can get it by running `lsusb` command)</br>
    `./bootloader.bin` is the Path of bootloader file.

Closed 2023-04-20.

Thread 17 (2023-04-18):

GPIO pinout on page 15 on Manual has unreadable labels

docdawning, 2023-04-18:
Page 15 on the manual has this diagram that labels the GPIO pins, but the labels are so blurred they can't be read.
Please replace the image with a higher resolution version so the pin names can be read.
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

DarKingF0x, 2023-04-18:
page 17 for my manual has a clearer picture here ya go
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

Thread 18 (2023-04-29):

Klipper Screen on 3.5 Inch TFT Screen

Doormat1, 2023-04-29:
Hi, I have a 3.5 inch screen that plugs into the GPIO pins, I have installed the relevant drivers via terminal but whilst the screen lights up I get nothing displaying the screen. Is this feature possible on this board or do I need the BTT screen?

DarKingF0x, 2023-04-29:
Did you uncomment the tft settings in the boardenv.txt (root of sdcard)?

Doormat1, 2023-04-30:
No will give that a try

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

DarKingF0x, 2023-04-30:
I had the same issue where my screen was completely White, I shut down my system powered It down unplugged it took the SD card out put it back in my PC edited the BoardEnv.txt and removed the # infront of tftspi section. Saved and reinserted the chip and it works perfectly fine after that. It may take a few moments, to show up but it should work

AlexWild74, 2023-12-29:
Hello, I have also  a BTT E3EZ with CB1. I have lines on the display, but KlipperScreen does not start. Can anyone help

Doormat1, 2023-12-29:
What screen are you using? In the end I gave up with the gpio screen, (pin order on the board is not the same as a pi I believe was the issue) and used the btt spi TFT screen. Works fine now.

AlexWild74, 2023-12-29:
I used a wave share 3.5" HDMI  and at first I used the screen with the narrow flat cable (SPI). The result were the same. So I think the problem is not the screen.

Doormat1, 2023-12-30:
Have you removed the # from the line in boardevn.txt? Also check your ribbon cable, the connectors can be mirrored. I found that I needed a ribbon cable where the pads are on the opposite sides

AlexWild74, 2023-12-30:
Yes, I think I did that. Here is how my display looks. See attached pic.
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

Doormat1, 2023-12-30:
Ah it's on the log in page. Have you read this https://klipperscreen.readthedocs.io/en/latest/Troubleshooting/

AlexWild74, 2023-12-30:
sadly I could not find one of the listed issues in my log.

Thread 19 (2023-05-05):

Heating issues

Wmelonhead, 2023-05-05:
I'm having trouble with the heating of my bed and nozzle.  I just installed the Manta E3EZ on my Ender 3 V2.  I previously had Klipper running on my raspberry pi and SKR Mini E3V3 on the same printer without any issues.  I have the Manta E3EZ installed with a CB1 and Klipper and Mainsail installed.

Everything appears normal.  However, when I print something, the bed and nozzle will both show in Mainsail that they are heating at the same time, when it is actually only heating the bed.   Then, after the bed hits 60 degrees, the nozzle will start heating, but the temperature for the bed will keep increasing in Mainsail, when it's not actually heating.  Once the bed temperature on Mainsail gets up to 130 or 150 degrees, the printer will shutoff.

If I change the nozzle thermister from TH0 to TH1 on the Manta, then the temperatures will act properly in Mainsail.  However, when I measure my bed temperature with my temperature gun, the bed will be about 15 degrees over 60 degrees.  When I measure the nozzle temperature, it will only be about 90 degrees, not 210.  As a result, my first layer tests are horrible.

I have also tried switching the extruder and power for the nozzle heater to the E1 connections, as well, with no results.

Can someone please help me with this issue.  I can't seem to find anyone else having this issue, so maybe I have just done something stupid?  I am attaching my printer.cfg file.  Thanks for any help.  And yes I know I have a lot of things in my config file.  I will create separate directories for them later and cut the fat.

[config-202344-202853.zip](https://github.com/bigtreetech/Manta-E3EZ/files/11403098/config-202344-202853.zip)
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

Wmelonhead, 2023-05-05:
Here is my config file if you don't want to open the zip:

[include mainsail.cfg]

#[include printer-ender3.cfg]

#[include macros.cfg]

# This file contains common pin mappings for the BIGTREETECH Manta E3EZ
# To use this config, the firmware should be compiled for the
# STM32G0B1 with a "8KiB bootloader" "8 MHz crystal"
# and "USB (on PA11/PA12)" or "CAN bus (on PB12/PB13)".

# See docs/Config_Reference.md for a description of parameters.

[stepper_x]
step_pin: PA14
dir_pin: !PA10
enable_pin: !PA13
microsteps: 16
rotation_distance: 39.800
endstop_pin: ^PC4
position_endstop: 0
position_max: 235
homing_speed: 50

[stepper_y]
step_pin: PC8
dir_pin: !PA15
enable_pin: !PC14
microsteps: 16
rotation_distance: 39.756
endstop_pin: ^PB0
position_endstop: 0
position_max: 235
homing_speed: 50

[stepper_z]
step_pin: PD2
dir_pin: !PD4
enable_pin: !PD3
microsteps: 16
rotation_distance: 7.967
endstop_pin: ^PC6
endstop_pin: probe:z_virtual_endstop
#position_endstop: 0
position_min: 0
position_max: 270

[stepper_z1]
step_pin: PD5
dir_pin: !PD6
enable_pin: !PB3
microsteps: 16
rotation_distance: 7.967
endstop_pin: ^PC6
endstop_pin: probe:z_virtual_endstop
#position_endstop: 0
#position_min: -5
#position_max: 270

[extruder]
step_pin: PB7
dir_pin: PB6
enable_pin: !PB4
microsteps: 16
rotation_distance: 7.583
nozzle_diameter: 0.400
filament_diameter: 1.750
pressure_advance: 0.0
pressure_advance_smooth_time: 0.040
heater_pin: PB10 #HE0
sensor_type: EPCOS 100K B57560G104F
sensor_pin: PA5 #TH0
#control: pid
#pid_Kp: 21.527
#pid_Ki: 1.063
#pid_Kd: 108.982
min_temp: 0
max_temp: 250
#   pressure_advance_smooth_time:  A time range (in seconds) to use when calculating the average
#   extruder velocity for pressure advance. A larger value results in
#   smoother extruder movements. This parameter may not exceed 200ms.
#   This setting only applies if pressure_advance is non-zero. The
#   default is 0.040 (40 milliseconds).
#PID_CALIBRATE HEATER=extruder TARGET=XXX (Whatever temp you print at)

#[filament_switch_sensor material_0]
#switch_pin: PC5

#[extruder1]
#step_pin: PB7
#dir_pin: PB6
#enable_pin: !PB4
#heater_pin: PB10 # HE1
#sensor_pin: PA5 # T1

#[filament_switch_sensor BTT]
#detection_length: 7
#extruder: extruder
#pause_on_runout: True
#This can be set to false to debug false positives putting the sensor in "monitor mode". The printer will not pause but it will run the runout_gcode below.
#switch_pin: ^PC5
#event_delay: 3.0
#pause_delay: 0.5
#runout_gcode:
    #M117 Runout Detected!

[filament_motion_sensor BTT]
detection_length: 10.00 ; This can be adjusted to your desired level of sensitivity. 10 is a recomended value to prevent flow dropoff false triggers.
extruder: extruder
switch_pin: ^PC5
pause_on_runout: True ; This can be set to false to debug false positives putting the sensor in "monitor mode". The printer will not pause but it will run the runout_gcode below.
event_delay: 3.0
pause_delay: 0.5
runout_gcode:
    M117 Runout Detected!

[delayed_gcode DISABLEFILAMENTSENSOR] ; This will disable the SFS 1 second after klipper starts
initial_duration: 1
gcode:
    SET_FILAMENT_SENSOR SENSOR=BTT ENABLE=0 ; Put your filament sensor's name after SENSOR=

[heater_bed]
heater_pin: PB2 #HB
sensor_type: EPCOS 100K B57560G104F #Generic 3950
sensor_pin: PA3 #TB
#control: pid
# tuned for stock hardware with 50 degree Celsius target
#pid_Kp: 76.222
#pid_Ki: 1.224
#pid_Kd: 1186.204
min_temp: 0
max_temp: 250
#PID_CALIBRATE HEATER=heater_bed TARGET=XXX

[fan]
pin: PA8

[heater_fan fan1]
pin: PB15

[heater_fan fan2]
pin: PB14

[mcu]
serial: /dev/serial/by-id/usb-Klipper_stm32g0b1xx_590028000C504B5735313920-if00

[virtual_sdcard]
path: /home/biqu/printer_data/gcodes

[printer]
kinematics: cartesian
max_velocity: 300
max_accel: 3000
max_z_velocity: 5
max_z_accel: 100
square_corner_velocity: 5.0
#   The maximum velocity (in mm/s) that the toolhead may travel a 90
#   degree corner at. A non-zero value can reduce changes in extruder
#   flow rates by enabling instantaneous velocity changes of the
#   toolhead during cornering. This value configures the internal
#   centripetal velocity cornering algorithm; corners with angles
#   larger than 90 degrees will have a higher cornering velocity while
#   corners with angles less than 90 degrees will have a lower
#   cornering velocity. If this is set to zero then the toolhead will
#   decelerate to zero at each corner. The default is 5mm/s.

########################################
# TMC2209 configuration
########################################

[tmc2209 stepper_x]
uart_pin: PB8
diag_pin: PC4
run_current: 0.596
hold_current: 0.516
stealthchop_threshold: 999999

[tmc2209 stepper_y]
uart_pin: PC9
diag_pin: PB0
run_current: 0.596
hold_current: 0.516
stealthchop_threshold: 999999

[tmc2209 stepper_z]
uart_pin: PD0
diag_pin: PC6
run_current: 0.596
#run_hold: 0.516
stealthchop_threshold: 999999

[tmc2209 stepper_z1]
uart_pin: PB5
diag_pin: PB1
run_current: 0.596
#run_hold: 0.516
stealthchop_threshold: 999999

#[tmc2209 extruder]
#uart_pin: PD1
#run_current: 0.800
#stealthchop_threshold: 999999

#[tmc2209 extruder1]
#uart_pin: PB5
#run_current: 0.800
#stealthchop_threshold: 999999

[board_pins]
aliases:
    # EXP1 header
    EXP1_1=PC1, EXP1_3=PC3, EXP1_5=PC0, EXP1_7=PA2, EXP1_9=<GND>,
    EXP1_2=PC2,  EXP1_4=<RST>, EXP1_6=PA0, EXP1_8=PA1, EXP1_10=<5V>

[bltouch]
sensor_pin: PA6
control_pin: PA7
x_offset: -29
y_offset: -41
#z_offset: 0 # Uncomment if starting fresh; Distance should be enough to keep the z-offset positive.
speed: 5.0
samples: 2
samples_result: median
sample_retract_dist: 6.0
samples_tolerance: 0.01
samples_tolerance_retries: 3

#[output_pin PS_ON]
#pin: PA9

#[output_pin pb9_pin]
#pin: PB9

#[neopixel my_neopixel]
#pin: PC7

[resonance_tester]
accel_chip: adxl345
probe_points:
    100, 100, 20   # an example
#max_smoothing:  0.25

[adxl345]
cs_pin: PC15
spi_software_miso_pin: PC11
spi_software_mosi_pin: PC12
spi_software_sclk_pin: PC10

[input_shaper]
shaper_freq_x: 52.6  # frequency for the X mark of the test model
shaper_freq_y: 49.2  # frequency for the Y mark of the test model
#shaper_type: mzv
shaper_type_x: mzv
shaper_type_y: 2hump_ei
#   If shaper_type is not set, these two parameters can be used to
#   configure different input shapers for X and Y axes. The same
#   values are supported as for shaper_type parameter.
damping_ratio_x: 0.1
damping_ratio_y: 0.1
#   Damping ratios of vibrations of X and Y axes used by input shapers
#   to improve vibration suppression. Default value is 0.1 which is a
#   good all-round value for most printers. In most circumstances this
#   parameter requires no tuning and should not be changed.

[bed_screws]
screw1: 30.5, 37
screw2: 30.5, 207
screw3: 204.5, 207
screw4: 204.5, 37

[display]
lcd_type: st7920
cs_pin: EXP1_7
sclk_pin: EXP1_6
sid_pin: EXP1_8
encoder_pins: ^EXP1_5, ^EXP1_3
click_pin: ^!EXP1_2

[output_pin beeper]
pin: EXP1_1

[safe_z_home]
home_xy_position: 117.5,117.5 # Change coordinates to the center of your print bed
speed: 100
z_hop: 10                 # Move up 10mm
z_hop_speed: 5

[bed_mesh]
speed: 120
horizontal_move_z: 5
mesh_min: 10, 37
mesh_max: 206, 183 # Make sure X,Y here meets these conditions (X+(bltouch+x_offset) < bed X) and (Y+(bltouch+y_offset) < Bed Y)
probe_count: 10,10
move_check_distance: 5
split_delta_z: 0.025
fade_start: 1
fade_end: 10
mesh_pps: 2, 2
algorithm: bicubic
#   The interpolation algorithm to use. May be either "lagrange" or
#   "bicubic". This option will not affect 3x3 grids, which are forced
#   to use lagrange sampling. Default is lagrange.
bicubic_tension: .2
#   When using the bicubic algorithm the tension parameter above may
#   be applied to change the amount of slope interpolated. Larger
#   numbers will increase the amount of slope, which results in more
#   curvature in the mesh. Default is .2.
#relative_reference_index:
#   A point index in the mesh to reference all z values to. Enabling
#   this parameter produces a mesh relative to the probed z position
#   at the provided index.
#faulty_region_1_min:
#faulty_region_1_max:
#   Optional points that define a faulty region.  See docs/Bed_Mesh.md
#   for details on faulty regions.  Up to 99 faulty regions may be added.
#   By default no faulty regions are set.

[z_tilt]
z_positions:  250, 117.5
              15, 117.5
#   A list of X, Y coordinates (one per line; subsequent lines
#   indented) describing the location of each bed "pivot point". The
#   "pivot point" is the point where the bed attaches to the given Z
#   stepper. It is described using nozzle coordinates (the X, Y position
#   of the nozzle if it could move directly above the point). The
#   first entry corresponds to stepper_z, the second to stepper_z1,
#   the third to stepper_z2, etc. This parameter must be provided.
points: 225,110
        40, 110
#   A list of X, Y coordinates (one per line; subsequent lines
#   indented) that should be probed during a Z_TILT_ADJUST command.
#   Specify coordinates of the nozzle and be sure the probe is above
#   the bed at the given nozzle coordinates. This parameter must be
#   provided.
speed: 150
#   The speed (in mm/s) of non-probing moves during the calibration.
#   The default is 50.
horizontal_move_z: 5
#   The height (in mm) that the head should be commanded to move to
#   just prior to starting a probe operation. The default is 5.
retries: 30
#   Number of times to retry if the probed points aren't within
#   tolerance.
retry_tolerance: 0.0025
#   If retries are enabled then retry if largest and smallest probed
#   points differ more than retry_tolerance. Note the smallest unit of
#   change here would be a single step. However if you are probing
#   more points than steppers then you will likely have a fixed
#   minimum value for the range of probed points which you can learn
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

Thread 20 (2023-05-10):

Bootloader missing

gabber130779, 2023-05-10:
HI, bootloader has been erased. i cant flash with sd card .
Can you share bootloader.bin with guide for flashing to recover my board?

Tina-Builds, 2023-05-20:
BTT finally added it to the firmware folder :-)

jbarron16, 2024-04-07:
Would we be able to get a guide on how to install the bootloader. I’m struggling on uploading the .bin file on the board. I have attempted WinSCP to the CB1 I have installed but run into permission issues for writing on the memory. Alternatively I’ve attempted manually adding the file to the BOOT SD card and running the line of code included but I receive genuinely errors and a failed flash .

PrintedVisionz3D, 2025-01-25:
I'm having the same issue, how to you transfer the bootloader bin to the CB1?

Tina-Builds, 2025-02-10:
> I'm having the same issue, how to you transfer the bootloader bin to the CB1?

The bootloader for the E3EZ has to be transferred to the E3EZ and not to the CB-1.
Just follow the instructions from: https://github.com/bigtreetech/Manta-E3EZ/tree/master/Firmware

5hiftyy, 2025-07-02:
I can't write the bootloader to the board either, even following those instructions on the page. It claims to have been completed successfully, but the bootloader and the firmware are both erased and neither are persistent after power cycling the board.

Closed 2023-05-27.

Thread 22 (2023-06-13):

"/serial/" directory restoration

BelowCelcius, 2023-06-13:
Hello, I am having troubles getting Klipper to connect to my Manta E3EZ's MCU. I'm trying to swap my Creality Ender 3 Neo's motherboard with the Manta & CB1 combo. I followed BigtreeTech's installation guide, but couldn't get the MCU to flash. I would get the "_mcu 'mcu': Unable to connect_" error on Mainsail.
 However, after doing some early troubleshooting, I managed to accidentally delete the "/serial/" file. I believe this is causing all the current trouble, and I can't figure out how to restore my "/serial/" file. Would anyone know if this is possible, and how so? Also, I still get the same previously mentioned error on Mainsail. I'll link my Klippy.log, and moonraker.log in this post as well. Please let me know if I should include anything else.

**Additional noteworthy symptoms:**

1. I can connect to the CB1 through SSH, and Mainsail.
2. I have made a "generic-bigtreetech-xxx" file.
3. In SSH, "make menuconfig" compiles a klippy.bin.
4. Firmware.bin doesn't change to FIRMWARE.CUR.
5. Cannot check to see if firmware has been updated correctly, because of no "/serial/" file.
6. There is no Klipper device ID.

[moonraker (4).log](https://github.com/bigtreetech/Manta-E3EZ/files/11739997/moonraker.4.log)
[klippy (13).log](https://github.com/bigtreetech/Manta-E3EZ/files/11739999/klippy.13.log)

Thanks
BelowCelcius

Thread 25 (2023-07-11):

Stepper driver SPI bus

agentmcmillan, 2023-07-11:
No documentation to connect the spi bus to motor drivers and how they map on the processor

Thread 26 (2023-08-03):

Manta E3EZ CB1 dual display BTT TFT35SPI and HDMI7 touch dont work at the same time

MetalWorks666, 2023-08-03:
Hi!

I have a problem how to figure out that both screens work at the same time. I am moving from MARLIN to KLIPPER with my new Manta E3EZ CB1 and dual screens BTT TFT35SPI and HDMI 7 touch. I can run only one screen at the same time... Any help will be appreciated.

[printer-ender3.txt](https://github.com/bigtreetech/Manta-E3EZ/files/12251139/printer-ender3.txt)

wildblue, 2024-02-27:
Same problem here.
If i use the file "sun50i-h616-biqu.dtb" instead of the standard -sd version in the bootenv.txt, my HDMI display shows only a small red Klipper Icon but nothing else. Using the original file my 3.5 spi TFT works just fine. I want to use both.

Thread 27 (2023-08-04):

Tutorial in the docs for EBB36 with Manta E3EZ as USB-to-CAN bridge

hauserkristof, 2023-08-04:
Dear BTT!

Please include a tutorial in the docs, how to set up the EBB36 board with the Manta E3EZ as a USB-to-CAN bridge.

It would be much appreciated! Until than, somebody can help me please? I'm a bit stuck on this...

Thank you,

Deapper, 2023-08-13:
This is a good video that might get you going. https://www.youtube.com/watch?v=EA-oBfenxAE&t=160s

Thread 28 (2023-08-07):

Can't update MCU

Deapper, 2023-08-07:
I followed the instructions for flashing the mcu with little success;

First I compiled the firmware with the 'make' command after make menuconfig settings as sighted in the manual.
```
cd ~/klipper/
make menuconfig
```
Changed the klipper.bin to firmware.bin and loaded onto a sdcard root.

Placed sdcard in MCU slot
Power off/on even tried the reset swicth.
After checking the sdcard either time I can not see firmware.cur only firmware.bin remains

Deapper, 2023-08-08:
Is anyone else able to update MCU by sdcard?

Deapper, 2023-08-13:
Not sure why I can't flash by sdcard... Used DFU mode. To get into DFU mode press and hold button on Manta board while power on

5hiftyy, 2025-07-02:
I am running into this same issue, but even flashing via DFU won't stick after a power cycle.

Closed 2023-08-13.

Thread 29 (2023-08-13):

CM4 + BTT TFT35 SPI V2.1

djeZo888, 2023-08-13:
I know that BTT TFT35 SPI V2.1 is advertised as display for CB1, but I am still wondering if there is any chance to use this display with CM4? If yes, please, what needs to be done. Thanks!

mhzpower, 2024-04-02:
I am interested too. I have a cm4 that I want to switch to but I would loose the screen if I do that.

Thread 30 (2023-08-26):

Unable to see MCU

Deapper, 2023-08-26:
Seem to have a new problem with my setup. I can't see my E3EZ board. I don't even see it with` ls /dev/serial/by-id/*`

If I enter into DFU mode I can see the E3EZ and I can flash the board and it starts working until next boot.

Deapper, 2023-08-26:
Canbus seems to have failed on my board. Now using USB with no problem

Closed 2023-08-26.

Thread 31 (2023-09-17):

STEP File doesn't load USB, ethernet or hdmi

elimisback, 2023-09-17:
When opening the step it is missing some of the components USB ethernet and hdmi at the least. These ports are important when designing custom cases.

BlueWings172, 2024-08-23:
@elimisback, @looxonline,

Did you guys find a complete 3D model? I am having the same issue. I am unable to design an enclosure for this board without a complete 3D model!

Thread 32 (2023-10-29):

USB connection in marlin

meysamsb, 2023-10-29:
I'm using E3Ez as a mainboard for a printer i have built from scratch (hypercube machine).
I'm using marlin as firmware.
The problem is when i try to connect the printer to my laptop via USB it doesn't connect and my laptop pointer starts to jitter

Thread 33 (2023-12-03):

Z_Endstop is always open

sabergo1, 2023-12-03:
The z endstop is always shown triggered when queried in mainsail m119.

I have a Beacon3d sensor configured as the virtual endstop.  The beacon module installed and nothing plugged into the z-endstop or BL-Touch pins.

The beacon sensor light triggers when brought into range of the bed and goes out when moved up (manually).  M119 status never changes.

Config File:

[mcu]
serial: /dev/serial/by-id/usb-Klipper_stm32g0b1xx_5E002D000C504B5735313920-if00

[include mainsail.cfg]

[stepper_x]
step_pin: PA14
dir_pin: !PA10
enable_pin: !PA13
microsteps: 16
rotation_distance: 40
endstop_pin: ^PC4
position_endstop: 0
position_max: 233
homing_speed: 50

[stepper_y]
step_pin: PC8
dir_pin: !PA15
enable_pin: !PC14
microsteps: 16
rotation_distance: 40
endstop_pin: ^PB0
position_endstop: 0
position_max: 234
homing_speed: 50

[stepper_z]
step_pin: PD2
dir_pin: !PD4
enable_pin: !PD3
microsteps: 16
rotation_distance: 8
gear_ratio: 2:1
endstop_pin: probe:z_virtual_endstop # use beacon as virtual endstop
homing_retract_dist: 0 # beacon needs this to be set to 0
#position_min: -5
position_max: 250

[extruder]
step_pin: PD5
dir_pin: PD6
enable_pin: !PB3
microsteps: 16
rotation_distance: 8.087 ##8.087 prusament asa; 8.168 3dxtech asa ##HemeraXS_7.6start##
nozzle_diameter: 0.400
filament_diameter: 1.750
heater_pin: PB11 #HE0
sensor_type: ATC Semitec 104NT-4-R025H42G
sensor_pin: PA4 #TH0
control: pid
pid_Kp: 21.527
pid_Ki: 1.063
pid_Kd: 108.982
min_temp: 0
max_temp: 250

########################################
# TMC5160 configuration
########################################

[tmc5160 stepper_x]
cs_pin: PB8
spi_software_miso_pin: PC11
spi_software_mosi_pin: PC12
spi_software_sclk_pin: PC10
##diag1_pin: PF3
run_current: 0.800
stealthchop_threshold: 999999
sense_resistor: 0.075

[tmc5160 stepper_y]
cs_pin: PC9
spi_software_miso_pin: PC11
spi_software_mosi_pin: PC12
spi_software_sclk_pin: PC10
##diag1_pin: PF4
run_current: 0.800
stealthchop_threshold: 999999
sense_resistor: 0.075

[tmc5160 stepper_z]
cs_pin: PD0
spi_software_miso_pin: PC11
spi_software_mosi_pin: PC12
spi_software_sclk_pin: PC10
##diag1_pin: PF5
run_current: 0.650
stealthchop_threshold: 999999
sense_resistor: 0.075

#[tmc5160 extruder]
cs_pin: PD1
spi_software_miso_pin: PC11
spi_software_mosi_pin: PC12
spi_software_sclk_pin: PC10
run_current: 0.800
stealthchop_threshold: 999999
sense_resistor: 0.075

[beacon]
serial: /dev/serial/by-id/usb-Beacon_Beacon_RevD_1AB2BF0A515137474C202020FF0C3A29-if00
x_offset: -14 # update with offset from nozzle on your machine
y_offset: +28 # update with offset from nozzle on your machine
mesh_main_direction: x
mesh_runs: 2

#[static_digital_output usb_pullup_enable]
#pins:

[bed_mesh]                    
speed: 150
mesh_min: 20, 20
mesh_max: 205, 205
algorithm: bicubic
probe_count: 5,5             
horizontal_move_z: 8

[safe_z_home]                 
home_xy_position: 117, 117
#speed: 100
z_hop: 3
#z_hop_speed: 5

#[filament_switch_sensor material_0]
#switch_pin: PC5

#[extruder1]
#step_pin: PB7
#dir_pin: PB6
#enable_pin: !PB4
#heater_pin: PB10 # HE1
#sensor_pin: PA5 # T1

#[filament_switch_sensor material_1]
#switch_pin: PB1

[heater_bed]
heater_pin: PB2 #HB
sensor_type: ATC Semitec 104GT-2
sensor_pin: PA3 #TB
control: pid
# tuned for stock hardware with 50 degree Celsius target
pid_Kp: 54.027
pid_Ki: 0.770
pid_Kd: 948.182
min_temp: 0
max_temp: 130

[fan]
pin: PA8

[heater_fan fan1]
pin: PB15

[heater_fan fan2]
pin: PB14

[printer]
kinematics: cartesian
max_velocity: 300
max_accel: 3000
max_z_velocity: 5
max_z_accel: 100

[board_pins]
aliases:
    # EXP1 header
    EXP1_1=PC1, EXP1_3=PC3, EXP1_5=PC0, EXP1_7=PA2, EXP1_9=<GND>,
    EXP1_2=PC2,  EXP1_4=<RST>, EXP1_6=PA0, EXP1_8=PA1, EXP1_10=<5V>

[bed_screws]
screw1: 33, 33
screw2: 33, 202
screw3: 202, 202
screw4: 202, 33

[screws_tilt_adjust]
screw1: 47, 5
screw1_name: front left screw
screw2: 216, 5
screw2_name: front right screw
screw3: 216, 174
screw3_name: rear right screw
screw4: 47, 174
screw4_name: rear left screw
horizontal_move_z: 10.
speed: 50.
screw_thread: CW-M4

[display]
lcd_type: st7920
cs_pin: EXP1_7
sclk_pin: EXP1_6
sid_pin: EXP1_8
encoder_pins: ^EXP1_5, ^EXP1_3
click_pin: ^!EXP1_2

[output_pin beeper]
pin: EXP1_1

[gcode_macro G29]                    # If moving from marlin to klipper uncomment to mimic G29
gcode:
  BED_MESH_CALIBRATE
# G1 X0 Y0 Z10 F4000

######################################################################
# Start Print and End Print
######################################################################

# Replace the slicer's custom start and end g-code scripts with
# START_PRINT and END_PRINT.

[gcode_macro START_PRINT]
gcode:
    {% set BED_TEMP = params.BED_TEMP|default(70)|float %}
    {% set EXTRUDER_TEMP = params.EXTRUDER_TEMP|default(245)|float %}
    # Start bed heating
    M140 S{BED_TEMP}
    # Use absolute coordinates
    G90
    # Reset the G-Code Z offset (adjust Z offset if needed)
    SET_GCODE_OFFSET Z=0.0
    # Home the printer
    G28
    # Move the nozzle near the bed
    G1 Z5 F3000
    # Move the nozzle very close to the bed
    G1 Z0.15 F300
    # Wait for bed to reach temperature
    M190 S{BED_TEMP}
    # Set and wait for nozzle to reach temperature
    M109 S{EXTRUDER_TEMP}

[gcode_macro END_PRINT]
gcode:
    # Turn off bed, extruder, and fan
    M140 S0
    M104 S0
    M106 S0
    #Move nozzle away from print while retracting
    G91
    G1 X-2 Y-2 E-3 F300
    #Raise nozzle by 10mm
    G1 Z10 F3000
    G90
    Disable steppers
    M84

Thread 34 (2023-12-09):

I upgraded to a Manta E3EZ and Melted the Y-axis Stepper Motor (housing) off my printer!

lugfug, 2023-12-09:
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
**The Problem:**
Let me tell you a charming story of melting plastic and destruction…

I have an “Ender 3 V2” with the OEM CREALITY control board and OEM Marlin.

I was using it to reliably make prints a couple of times a week.

The hardware upgrades are as follows:
(All were installed and working with the OEM CREALITY control board and OEM Marlin.)
-  CREALITY Dual Z Motors (originally driven from one driver motor, via wire splitter, from the OEM control board.)
- Micro Swiss NG™ REVO Direct Drive Extruder
- BLTouch

**Need For Speed:**
I wanted to upgrade to Klipper to gain more speed, control over the printing process and Dual Z tramming.

So I installed a “BTT Manta E3EZ” control board with five “EZ2209” drivers and a “BTT CB1”

The physical install was painless and normal

I used the “printer-ender3.cfg” provided on the Manta E3EZ GitHub page and included it in my “printer.cfg”

So far So Good… or so I thought

**The "Great Melting":**
When I was configuring the BLTouch in the .cfg file, I started to smell the distinct aroma of melting ABS (not an electrical smell, nope, it was clearly melting ABS)… and the power supply fan unexpectedly turned on, even though the stepper motors were not moving.

I thought _“hmm, that smell is odd… the power supply must be ‘burning off some dirt’…I wonder why the power supply fan is running…”_ **SMH** 🤦🏻‍♂️

I went back to configuring Klipper from my laptop.

Then I realized the Y-axis motor would intermittently “quiver”, jiggling the print bed maybe a fraction of a millimeter.

I thought _“hmm, that is odd, I wonder if my config file changes are causing it to spaz out… boy that ABS smell kinda stinks…”_ **SMH** 🤦🏻‍♂️ (not yet seeing the problem.)

I watched a few more minutes of my YouTube video for setting up the BLTouch and made a couple of `printer.cfg` edits.

Trying to home the Y-axis this time revealed a “loose belt” and the Y-axis motor wasn’t moving the print bed.

I tightened the Y-axis belt tensioner and no amount of tightening would make the belt tighten up.

I thought _“hmm, that is odd, how did the belt get so loose?… Geez, that ABS smell REALLY stinks…”_ **SMH** 🤦🏻‍♂️ (STILL not seeing the problem.)

Looking under the bed I caught a glimpse of **_“movement”._**

I thought _“Wait, what the heck is moving at the back of the printer…??!??!??”_

Just then, I see the Y-axis motor **FALL OFF THE PRINTER!**

**“Oh S#¡7 !!!,

WHAT THA F*@#!!!!!

GOD DAM*& IT!!!!!!,

YANK THE F’ING POWER CORD!!!!!!!!!”**

There in front of me, laid the melted, contorted remains of my ABS, Y-axis motor mount…
(pics below)

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

The stepper motor slumped to the table with a thud and the flaccid belt drooped helplessly over the carnage.

**DOH!** 🤦🏻‍♂️

Still no electrical fire smell just melted ABS (which melts at 105 °C)

The motor was hot enough to give you a serious burn.

Traumatized, I took the rest of the night off, no more 3D printers for me, _“GOD that ABS STINKS!”_

**Hardware Solution:**
Vowing to never repeat the “Great Melting of 2023”, I built a Y-axis motor mount out of a fence post that I bought at Home Depot which was 2”x2”, hollow, and MOST importantly it was ALL METAL!!!
(pics below)

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

No more melting my motor off and yanking the power cord in a panic, LOL.

You can buy your very own 3 foot fence post to make your own ALL METAL motor mount here
 https://www.homedepot.com/p/2-in-x-2-in-x-3-ft-Black-Metal-Fence-Post-with-Flange-and-Post-Cap-58285247/324829989

**What Went Wrong???:**
Beats the F’ out of me…

Maybe you know what I totally messed up.

I’ll include my existing config file below for your review.

I’d love to make a few prints, or at the lease keep the damn thing from setting itself on fire!

**_Seriously though_**, would you look at my config file and offer your thoughts of how I could properly set up the printer … and avoid any further meltdowns?

THANK YOU for helping a fellow Maker in Need.

**Lugfug**

NOTE: Here are the Model Numbers of the Stepper Motors just in case that is helpful.

X:	BJ42D15-26V10 LOT NO.200525G 		(CREALITY part)
Y: 	BJ42D15-26V09 LOT NO.20006F		(CREALITY part)
Z: 	BJ42D15-26V10 LOT NO.200523D		(CREALITY part)
Z1:	BJ42D15-26V12 LOT NO.230306A1		(CREALITY part)
E: 	LDO-42STH25-1404AC(MSL) 221114	(LDO Motors part)

Current Config File:
```
# This file contains common pin mappings for the BIGTREETECH Manta E3EZ
# To use this config, the firmware should be compiled for the
# STM32G0B1 with a "8KiB bootloader" "8 MHz crystal"
# and "USB (on PA11/PA12)" or "CAN bus (on PB12/PB13)".

# See docs/Config_Reference.md for a description of parameters.

[stepper_x]
step_pin: PA14
dir_pin: !PA10
enable_pin: !PA13
microsteps: 16
rotation_distance: 40
endstop_pin: ^PC4
position_endstop: 0
position_max: 235
homing_speed: 50

[stepper_y]
step_pin: PC8
dir_pin: !PA15
enable_pin: !PC14
microsteps: 16
rotation_distance: 40
endstop_pin: ^PB0
position_endstop: 0
position_max: 235
homing_speed: 50

[stepper_z]
step_pin: PD2
dir_pin: !PD4
enable_pin: !PD3
microsteps: 16
rotation_distance: 8
endstop_pin: probe:z_virtual_endstop
#position_endstop: 0.0
position_max: 250
position_min: -6.0

[extruder]
step_pin: PD5
dir_pin: PD6
enable_pin: !PB3
microsteps: 16
rotation_distance: 33.500
nozzle_diameter: 0.400
filament_diameter: 1.750
heater_pin: PB11 #HE0
sensor_type: ATC Semitec 104NT-4-R025H42G
sensor_pin: PA4 #TH0
control: pid
pid_Kp: 21.527
pid_Ki: 1.063
pid_Kd: 108.982
min_temp: 0
max_temp: 250

#[filament_switch_sensor material_0]
#switch_pin: PC5

#[extruder1]
#step_pin: PB7
#dir_pin: PB6
#enable_pin: !PB4
#heater_pin: PB10 # HE1
#sensor_pin: PA5 # T1

#[filament_switch_sensor material_1]
#switch_pin: PB1

[heater_bed]
heater_pin: PB2 #HB
sensor_type: EPCOS 100K B57560G104F #Generic 3950
sensor_pin: PA3 #TB
control: pid
# tuned for stock hardware with 50 degree Celsius target
pid_Kp: 54.027
pid_Ki: 0.770
pid_Kd: 948.182
min_temp: 0
max_temp: 130

[fan]
pin: PA8

[heater_fan fan1]
pin: PB15

#[heater_fan fan2]
#pin: PB14

[mcu]
serial: /dev/serial/by-id/usb-Klipper_stm32g0b1xx_22002D0002504B5735313920-if00

[temperature_sensor CB1]
sensor_type: temperature_host

[temperature_sensor MANTA_E3EZ]
sensor_type: temperature_mcu
min_temp: 0
max_temp: 100

[temperature_fan Case_fans]
pin: PB14
sensor_type: temperature_host
off_below: 0.4
min_temp: 10
max_temp: 90
target_temp: 55
control: pid
pid_Kp: 2
pid_Ki: 4
pid_Kd: 0.1

[printer]
kinematics: cartesian
max_velocity: 300
max_accel: 3000
max_z_velocity: 5
max_z_accel: 100

########################################
# TMC2209 configuration
########################################

#[tmc2209 stepper_x]
#uart_pin: PB8
##diag_pin: PC4
#run_current: 0.800
#stealthchop_threshold: 999999

#[tmc2209 stepper_y]
#uart_pin: PC9
##diag_pin: PB0
#run_current: 0.800
#stealthchop_threshold: 999999

#[tmc2209 stepper_z]
#uart_pin: PD0
##diag_pin: PC6
#run_current: 0.650
#stealthchop_threshold: 999999

#[tmc2209 extruder]
#uart_pin: PD1
#run_current: 0.800
#stealthchop_threshold: 999999

#[tmc2209 extruder1]
#uart_pin: PB5
#run_current: 0.800
#stealthchop_threshold: 999999

[board_pins]
aliases:
    # EXP1 header
    EXP1_1=PC1, EXP1_3=PC3, EXP1_5=PC0, EXP1_7=PA2, EXP1_9=<GND>,
    EXP1_2=PC2,  EXP1_4=<RST>, EXP1_6=PA0, EXP1_8=PA1, EXP1_10=<5V>

[bltouch]
sensor_pin: PA6
control_pin: PA7
x_offset: -30
y_offset: -10
samples: 2
speed: 2
z_offset: 0.0

[safe_z_home]
home_xy_position: 80,50 #Change coordinates to the center of your bed.
speed: 50
z_hop: 10 #Move up 10mm
z_hop_speed: 5

#[output_pin PS_ON]
#pin: PA9

#[output_pin pb9_pin]
#pin: PB9

#[neopixel my_neopixel]
#pin: PC7

#[adxl345]
#cs_pin: PC15
#spi_software_miso_pin: PC11
#spi_software_mosi_pin: PC12
#spi_software_sclk_pin: PC10

[bed_screws]
screw1: 30.5, 37
screw2: 30.5, 207
screw3: 204.5, 207
screw4: 204.5, 37

[display]
lcd_type: st7920
cs_pin: EXP1_7
sclk_pin: EXP1_6
sid_pin: EXP1_8
encoder_pins: ^EXP1_5, ^EXP1_3
click_pin: ^!EXP1_2

[output_pin beeper]
pin: EXP1_1
```

dkustec, 2024-01-05:
Most humorous storytelling issue on GH I ever saw. 💕

billatgit, 2024-02-21:
remember to uncomment the lines (remove the #)
[tmc2209 stepper_y]
uart_pin: PC9
run_current: 650
stealthchop_threshold: 999999

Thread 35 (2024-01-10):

USB Not recognized at all

wil-sys, 2024-01-10:
I have a manta E3Ez and a CM4 Lite, 2GB Ram, Wifi. However recently I cannot detect anything over USB, not even the MCU or USB hub itself. Ive made sure to add “ dtoverlay=dwc2,dr_mode=host” and I have confirmed that there is 5v output from the USB ports, but nothing is detected at all.

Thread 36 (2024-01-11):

Unable to set run_current without triggering weird behaviour

Givemeurcookies, 2024-01-11:
Hello, I have upgraded my Creality CR-10 with the Manta E3EZ and EZ2209 and got everything working.
I however had issues with all the steppers overheating (i.e the extruder melts the PLA when trying to extrude)

Based on the documentation I have to adjust the `run_current` in Klipper to have the EZ2209 driver limit the current to the steppers.
This is where I got some weird behaviour when setting the `run_current`  in Klipper, if I set (taking the x motor as an example):
```
[tmc2209 stepper_x]
uart_pin: PB8
# diag_pin: PC4
run_current: 0.800
stealthchop_threshold: 999999
```

After setting this config the stepper on that axis moves about 50% of the distance when homing compared to when the configuration isn't set + there is more coil whine and the steppers move really slowly. In addition, after some debugging makes it seem like changing the `uart_pin: PB8` doesn't have any effect. Is this the correct pin for UART for the x stepper? It almost seems like when the default values set the uart_pin to the correct values.

If I comment out the config above, the steppers suddenly behave as expected but then I have the overheating issue again. Even if I set the stepper run_current to the max 2A it doesn't make difference.

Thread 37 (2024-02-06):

Runaway temperatures for bed and extruder right from start

ikarus-71, 2024-02-06:
Hi,

I have been using Ender S1 with Klipper quite some time and decided to change the board with a Manta E3EZ CB1 for its extended connection options. I mapped all the connections to the new board and installed OS. However in mainsail, I see the temperatures start quite high as I turn on the board,  although physically board or extruder are not heated.

I know that thermistors are working fine, ı triple checked the connections. Bed thermistor is connected to TB connection, extruder thermistor is connected to TH1. Followng are my extruder and heater bed sections

[extruder]
step_pin: PD5
dir_pin: PD6
enable_pin: !PB3
microsteps: 16
gear_ratio: 42:12
rotation_distance: 26.359
nozzle_diameter: 0.400
filament_diameter: 1.750
heater_pin: PB11 #HE0
sensor_type: EPCOS 100K B57560G104F
sensor_pin: PA4 #TH0
control: pid
pid_Kp: 24.882
pid_Ki: 1.610
pid_Kd: 96.106
min_temp: 0
max_temp: 300

[heater_bed]
heater_pin: PB2 #HB
sensor_type: EPCOS 100K B57560G104F #Generic 3950
sensor_pin: PA3 #TB
control: pid
# tuned for stock hardware with 50 degree Celsius target
pid_Kp: 70.482
pid_Ki: 1.702
pid_Kd: 729.484
min_temp: 0
max_temp: 150

Any help will be appreciated!

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

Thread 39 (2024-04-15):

CAN Klipper reserved pin problem EBB36v1.2 / Manta E3EZ

cs301cs301, 2024-04-15:
I have the problem that some of the specified pins are already reserved for CAN. This means that I cannot use the ADXL cs_pin: EBBCan:PB12. Klipper gives error, is reserved for CAN. The E3EZ uses PB12 and PB13 for CAN communication.
I also cannot use the heater_pin: EBBCan:PB13, also reserved for CAN.
So can I not use CAN in this board combination?
I shortly had the idea of using the unused EXP port, pin PC2 and PC3, but I'm missing the R120 there.
I had hoped to have an improvement with this board, but in retrospect the purchase was a bad decision, even for the EBB36v1.2.

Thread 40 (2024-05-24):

Bed wont heat

destruct123, 2024-05-24:
Just upgraded my ender 3 max. Everything works fine, but the bed wont heat even a celsius. think my board come dead.
[config-20240524-084117.zip](https://github.com/bigtreetech/Manta-E3EZ/files/15433692/config-20240524-084117.zip)

mast3rmindx, 2025-02-06:
Facing the same issue. Was it a dead board?

STATEDLIGHT, 2025-02-06:
Old post but just found it as I'm having same issue after around a year.  My bed isn't heating anymore.

mast3rmindx, 2025-02-06:
My first board had this issue fresh out the box, now the replacement board is having the same issue. Has to be a design flaw or bad quality checking.

STATEDLIGHT, 2025-02-06:
I've worked out why it's not heating, the fuse has blown.

mast3rmindx, 2025-02-06:
The 10AMP white mini fuse?

STATEDLIGHT, 2025-02-06:
15amp one next to the power for the bed

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

mast3rmindx, 2025-02-10:
I have replacement fuses I changed it still didn’t fix it for me

STATEDLIGHT, 2025-02-10:
My fuses haven't arrived yet but it's likely because I used too thin a gauge of wire between my PSU and the board.  I have my board in a case at the side of my printer.  About 3 or 4 days before the fuse blew I extended that cable so I suspect it wasn't thick enough and caused the fuse to blow so have ordered some thicker gauge wire also.  We will see 🤞

mast3rmindx, 2025-02-10:
Fingers crossed for you! I ended up using one of the fan ports to control an external mosfet for the heated bed so you have options if it doesn’t get fixed by replacing the fuse.

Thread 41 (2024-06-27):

Can Problem Manta E3EZ+CM4 with FLY-SHT36 v2

KarloKlemen, 2024-06-27:
Pin PB13 reserved for CAN - can't reserve for spi2.
I tried everything different configs with updating klipper and flashing it multiple times nothing and still get this message.
Here is log from klippy. Can some help?

[klippy (2).log](https://github.com/user-attachments/files/16009339/klippy.2.log)

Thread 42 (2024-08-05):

Installing the Manta E3Ez board into the Ender 5 pro case.

Kuzja27, 2024-08-05:
Has anyone installed the board into the Ender 5Pro case using power supply adapters? I printed the adapter from the attached file in the Ender5 folder. If you have a couple of photos of the process or a description I would be very grateful. For those who haven't printed yet. You need two adapters.

samschultzponsys, 2024-09-25:
I am in the same boat, I do not really see how these stl brackets will help me with space in my E5

Kuzja27, 2024-10-03:
Here's a look at how I did it. You need to print two fasteners. The bolts (from the printer manufacturer) that are used to attach the power supply to the printer case, you use to attach the printed parts to the printer block. To attach the power supply with the printed parts to the printer case, you will additionally need 3 bolts and 3 nuts. Bolts M3 or M2 and approximately 15-20 mm long. Or use the bolts that you have available.
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

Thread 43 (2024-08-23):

Incomplete 3D Model of the E3EZ Board

BlueWings172, 2024-08-23:
Hello everyone,

I just downloaded the 3D model of the E3EZ board from this repository, but I noticed that it’s missing several key components, such as the Ethernet and USB ports and the stepper drivers. As I’m planning to design an enclosure for the board, having these details is crucial for accurate fitting.

Does anyone know where I can find a more complete 3D model that includes these components? Any help or pointers would be greatly appreciated!

Thank you in advance!

fischer-felix, 2024-10-20:
Same with me, I would also really like the complete model.

I have done some investigating with the pdf that is also provided. It is a pdf with embedded 3d model (viewable with Adobe Acrobat).

My efforts converting this pdf to anything useable have not really lead to much yet.

Ideally BigTreeTech would just share a complete step (or other common format) file of the product.

BTTJUSTIN, 2024-10-23:
Thanks for reporting. We will get the documentation updated and close this issue out once the updates are uploaded.

fischer-felix, 2024-10-31:
That would be great if you could upload the complete step file.

Is it possible to get a rough timeline on this, as I am currently in the process of setting up my printer with an E3EZ, and it would be very helpful to have the 3d model to design a custom enclosure.
So if it still may take some time, I might as well get started designing right away and make do with the incomplete model.

BTTJUSTIN, 2024-12-24:
Apologize for the late reply, Please check for link for the 3d model file
https://we.tl/t-D494Q5q2dA

BlueWings172, 2025-01-01:
@BTTJUSTIN
Thanks for sharing the new model. I tried to downlead but the link doesn't work anymore. Would be possible to share the link again ?

Many thanks

fischer-felix, 2025-01-01:
@BlueWings172 it seems the file in the GitHub repo in the folder 3D has also been updated, so you can just download it from there.

Closed 2025-01-25.

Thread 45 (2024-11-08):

Problem with booting CB2

WEBOWNIA, 2024-11-08:
I have an issue with booting CB2. I'm following: https://www.youtube.com/watch?v=XfZppjHU0ak

The difference is that I haven't connected a monitor because I don't yet have an HDMI adapter and am waiting for it to arrive. So, I can't see what's going on there...

I'm expecting to see the device name on the list of connected devices, but nothing appears, so I'm assuming either Klipper isn't starting for some unknown reason, or maybe I'm doing something wrong.

WEBOWNIA, 2024-11-08:
Is there any way to check if the board and CB2 are not damaged?

I should add that I bought new units. I connected and fastened them with small M2 screws according to the instructions.

I connected the WiFi antenna.

I plugged in a 24V power supply, as that’s also recommended.

I also tried connecting via USB OTG cable by switching the DPDT switch and bridging jumpers 3 (USBOTG) and 4 (RPIBOOT) to flash using RKDevTool. Unfortunately, the computer doesn’t detect anything. I also tried uninstalling and reinstalling the included USB drivers. (Windows 10 Pro)

I’ll add that when I apply power, the red LED stays lit, so it seems like there’s some life in it.

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

Closed 2024-11-14.

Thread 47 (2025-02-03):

Extruder Motor not moving

tonyown, 2025-02-03:
There is no communication at all between the motherboard and the extruder motor. Checked wires and they are good and well plugged, checked pins number in config. Can’t figure out what happen..

Ender 3 max
Sprite pro
Manta e3ez

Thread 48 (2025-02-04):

can I connect a MAX31855 to SPI3 and assign it as an Enclosure temp. sensor in klipper

HappyTechnician, 2025-02-04:
I want to heat my printer enclosure. I will use the TH1 for the heater_sensor and FAN2 for the temperature_fan. I want to have a temperature_sensor for the chamber.. I want to use SPI3 for this...

HappyTechnician, 2025-02-12:
Self answered:  The chamber is being heated with HE1 through an SSR to a 110VAC PTC heater, and TH1 is the sensor on the heater for safety. A BME680 is used for ambient chamber temperature, along with a MAX31865 sensor amplifier ... there is also an exterior BME280 ambient room temperature sensor. that system is working well.

Closed 2025-02-19.

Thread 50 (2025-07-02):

Can't flash MCU persistently, via SD card or DFU

5hiftyy, 2025-07-02:
Flashing firmware onto the E3EZ board was not successful using either the SD card or DFU methods.

For the SD card flash, the firmware would not be changed from `firmware.bin` to `firmware.cur`, as stated it should in the manual. The manual was followed for all steps.

### For DFU:
Issuing command `lsusb`

spajo, 2025-09-13:
hey @5hiftyy I had a similar issue today. The board went into DFU but it always errored out when flashing with following message
```
Determining device status...
dfu-util: error get_status: LIBUSB_ERROR_TIMEOUT
```
This has previously worked for me so not sure what happened.

SD Card also wouldn't work for me because I followed the manual. Manual says to put in the SD Card (MCU slot) and either power-on or click RST key. Both didn't work for me. Only when I held BOOT when powering on and then clicked RST ([bootloader instructions](https://github.com/bigtreetech/Manta-E3EZ/blob/master/Firmware/README.md)), the blue LED flashed 3 times and firmware was flashed.
Hope it helps.

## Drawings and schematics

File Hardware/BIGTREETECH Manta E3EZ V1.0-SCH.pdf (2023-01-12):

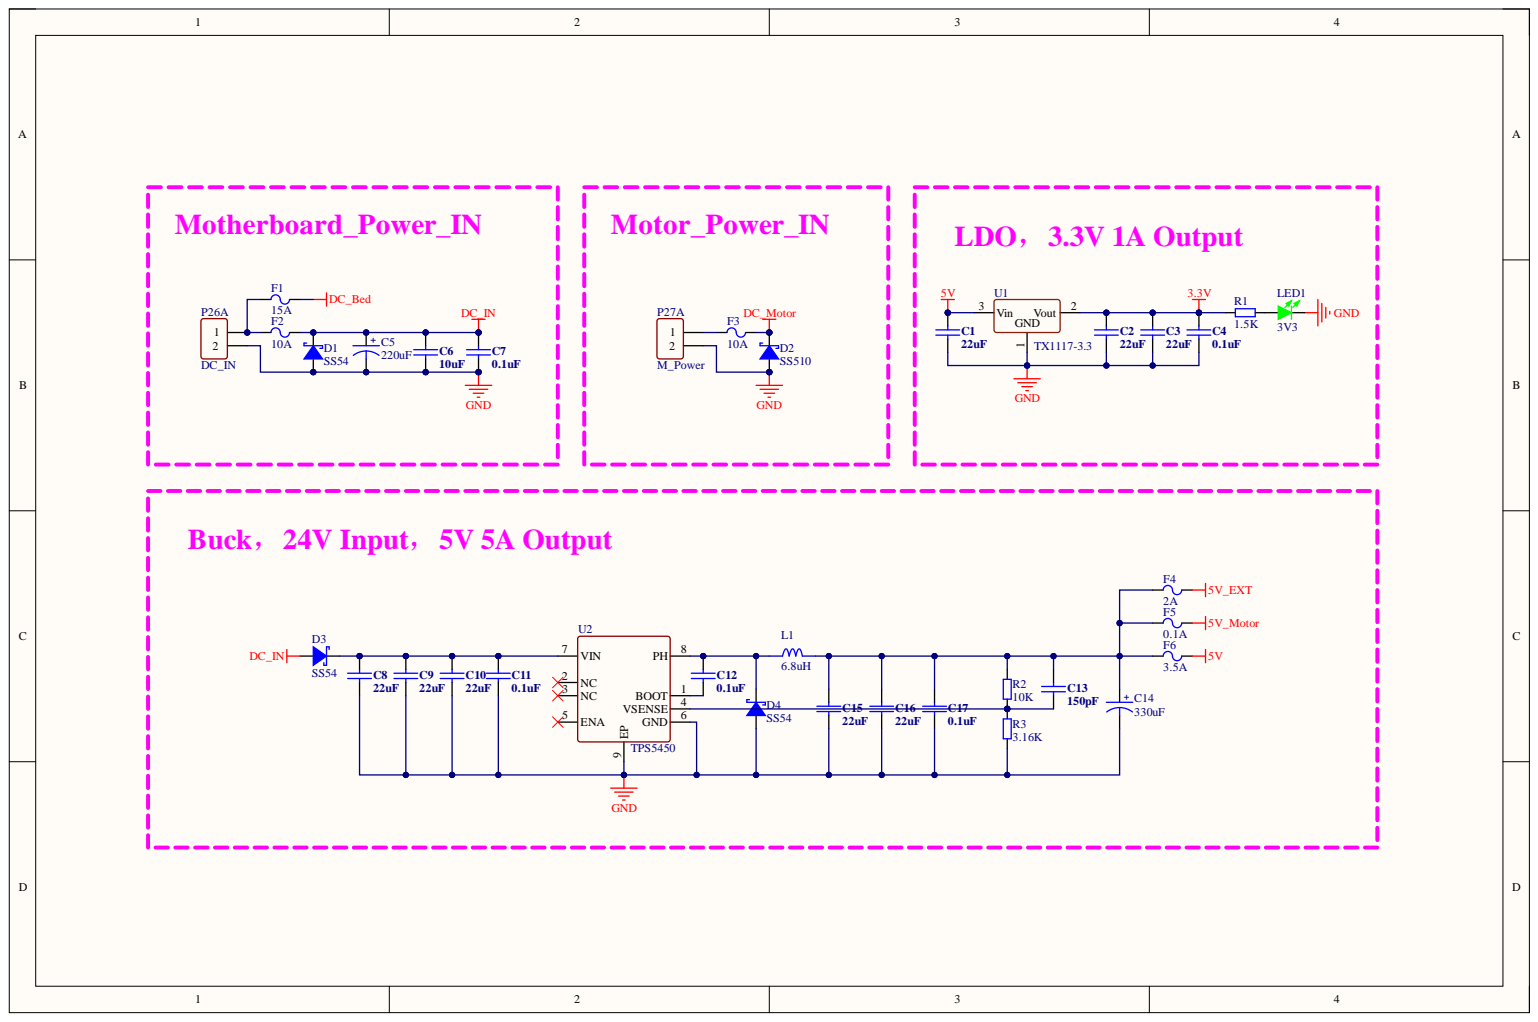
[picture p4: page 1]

ENA 5

TPS5450

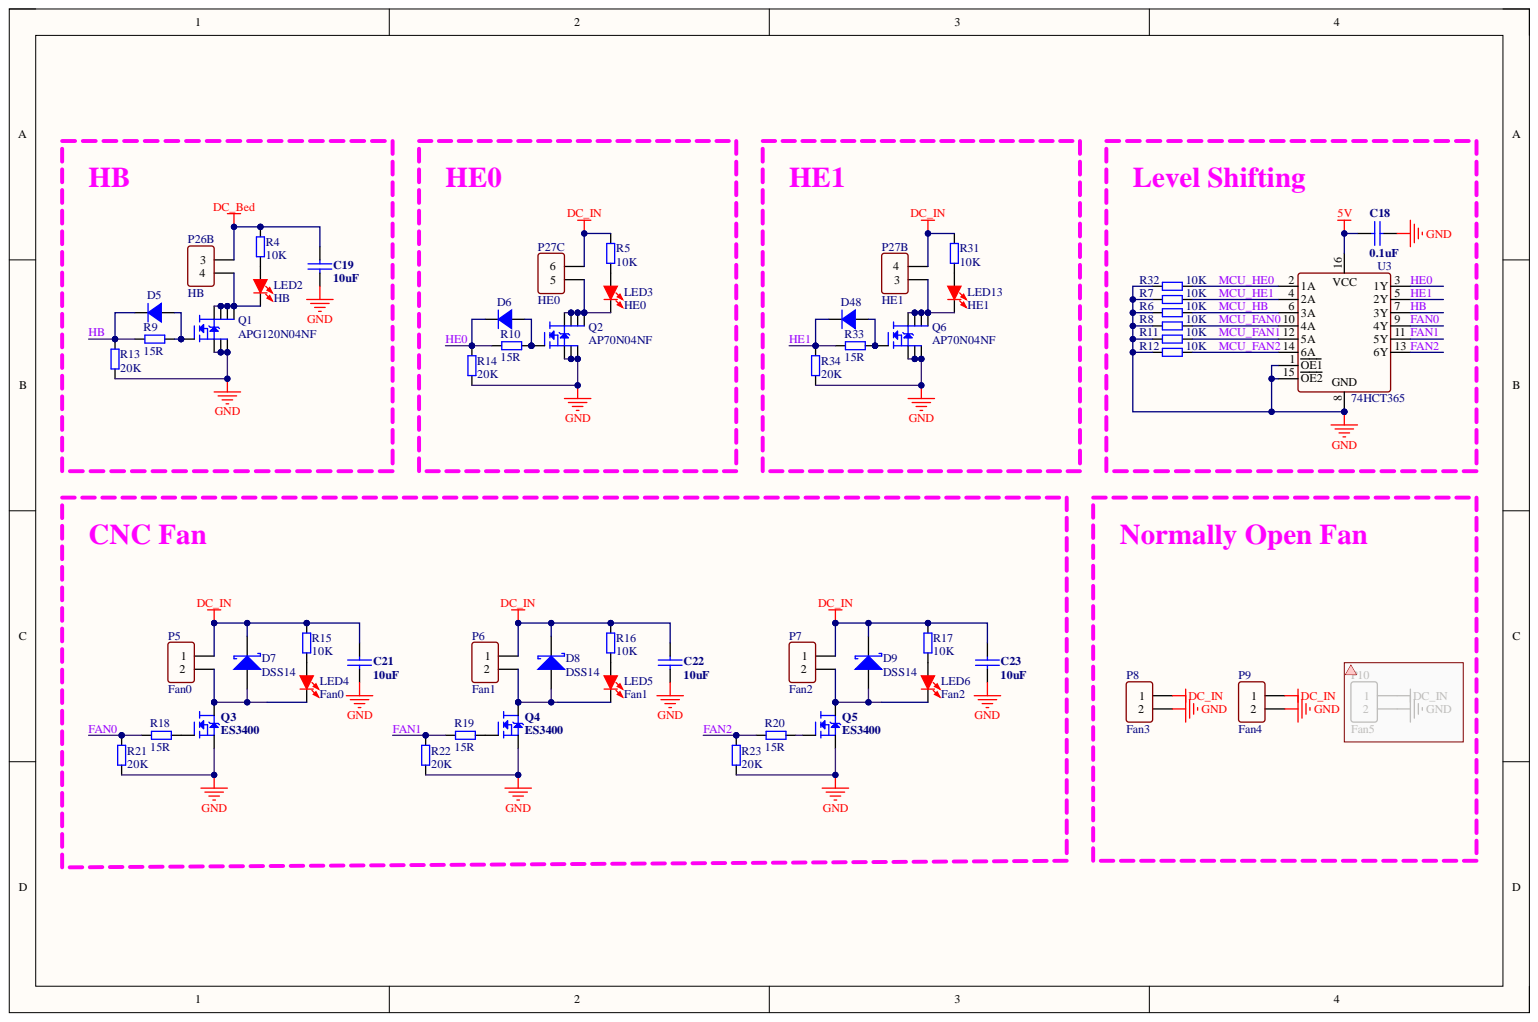
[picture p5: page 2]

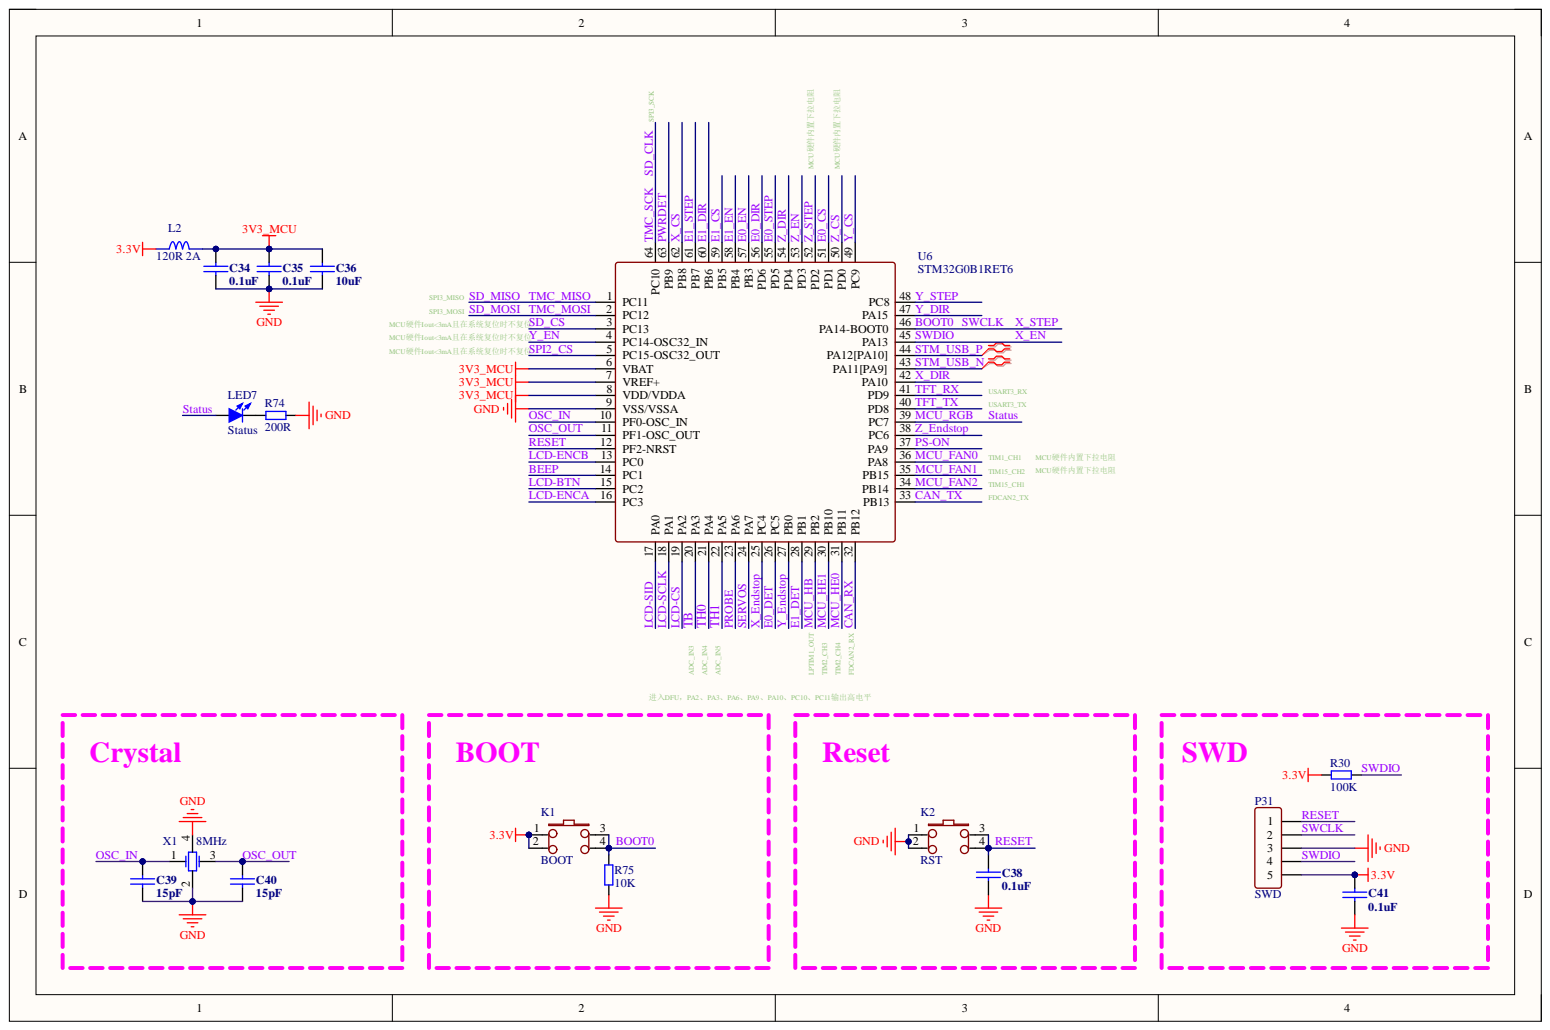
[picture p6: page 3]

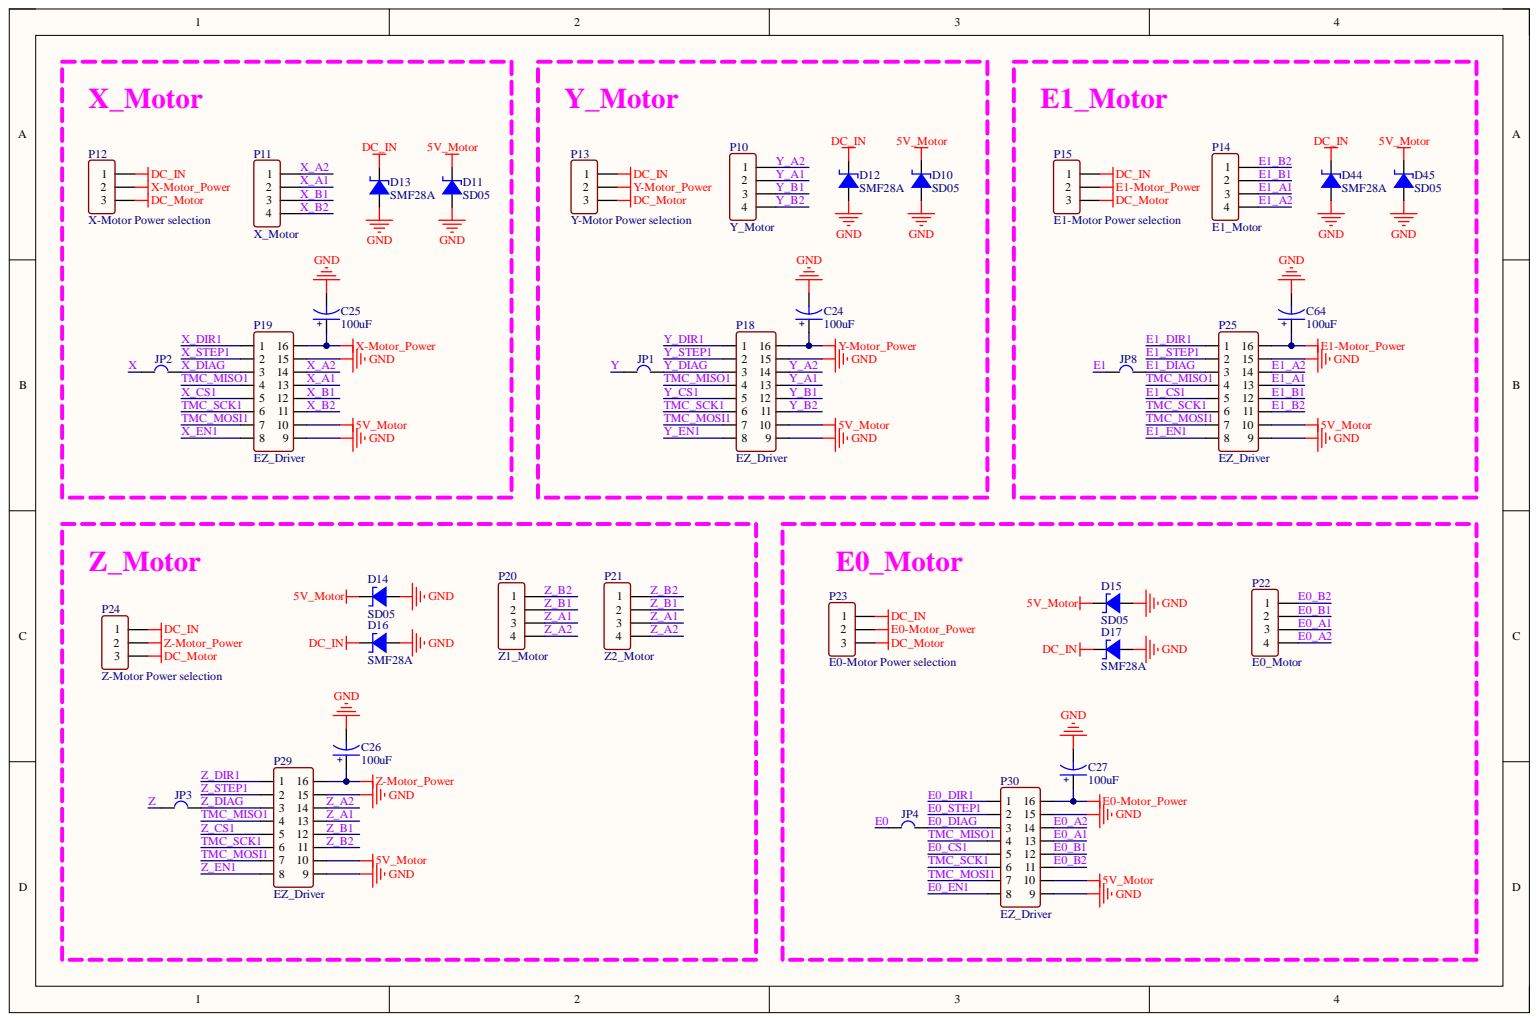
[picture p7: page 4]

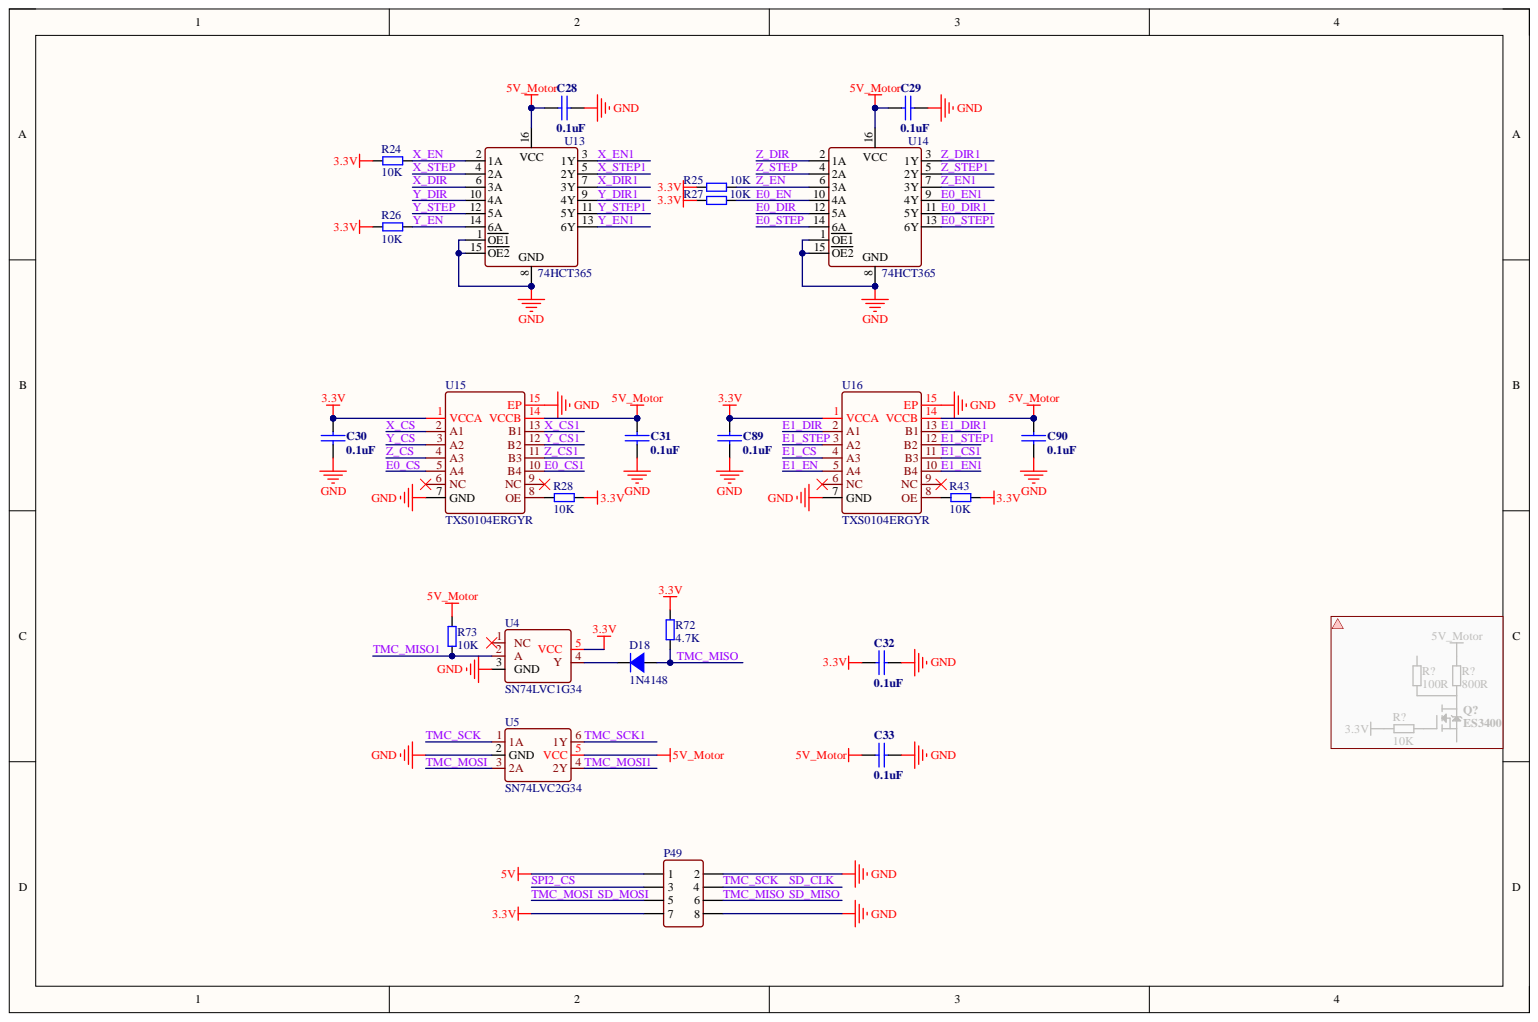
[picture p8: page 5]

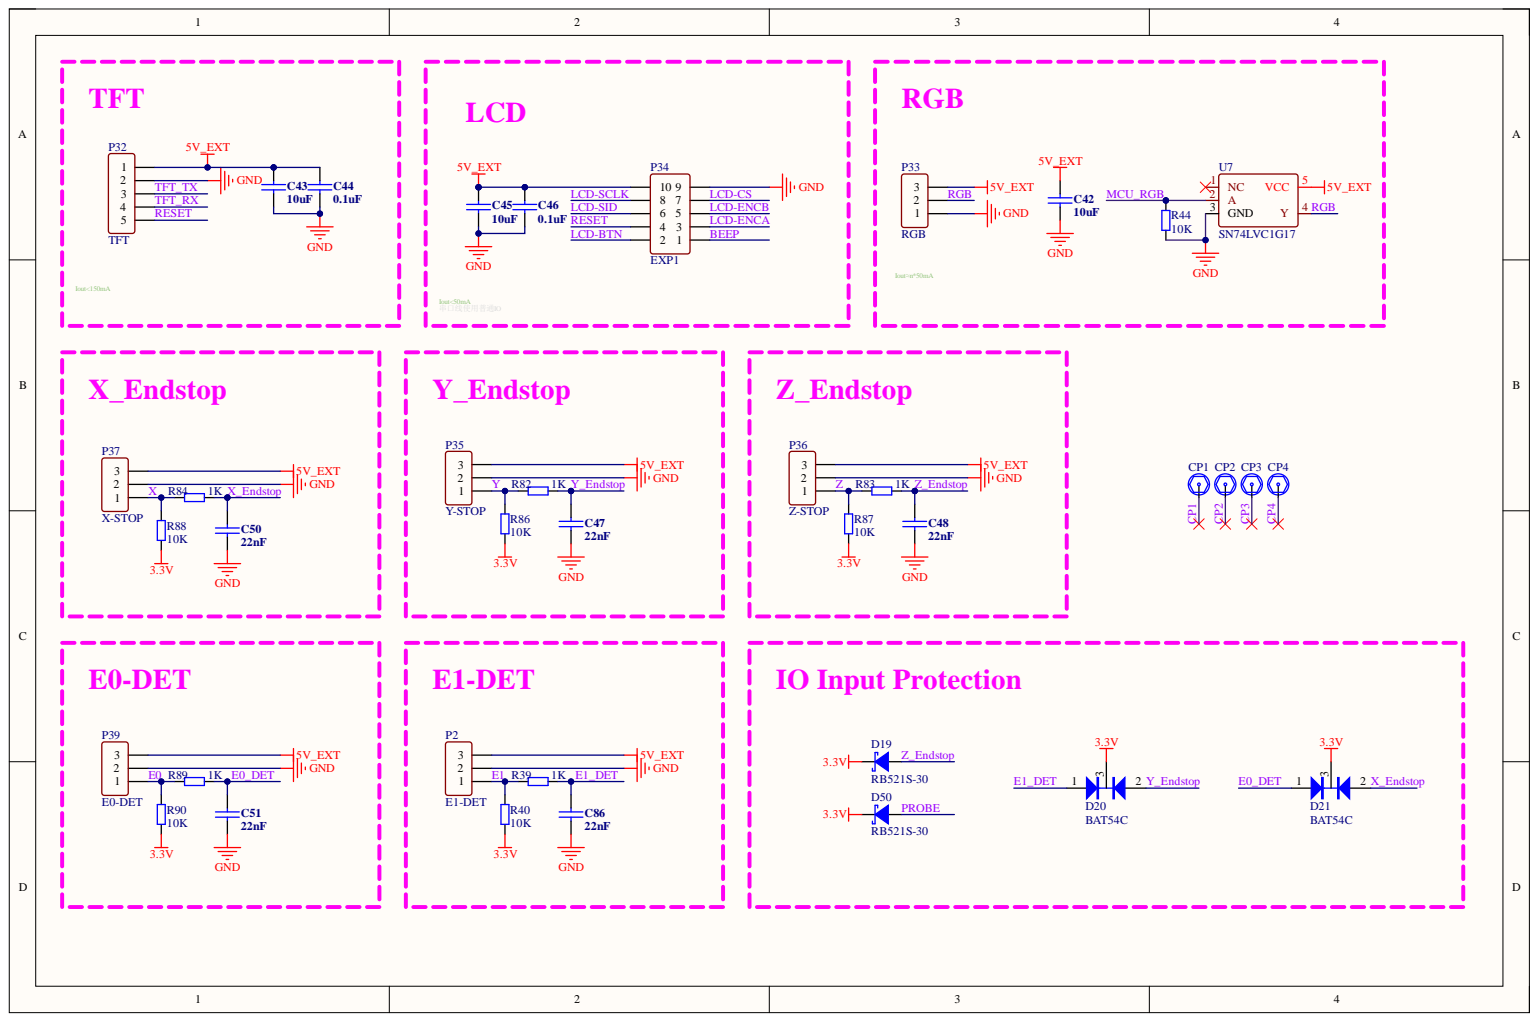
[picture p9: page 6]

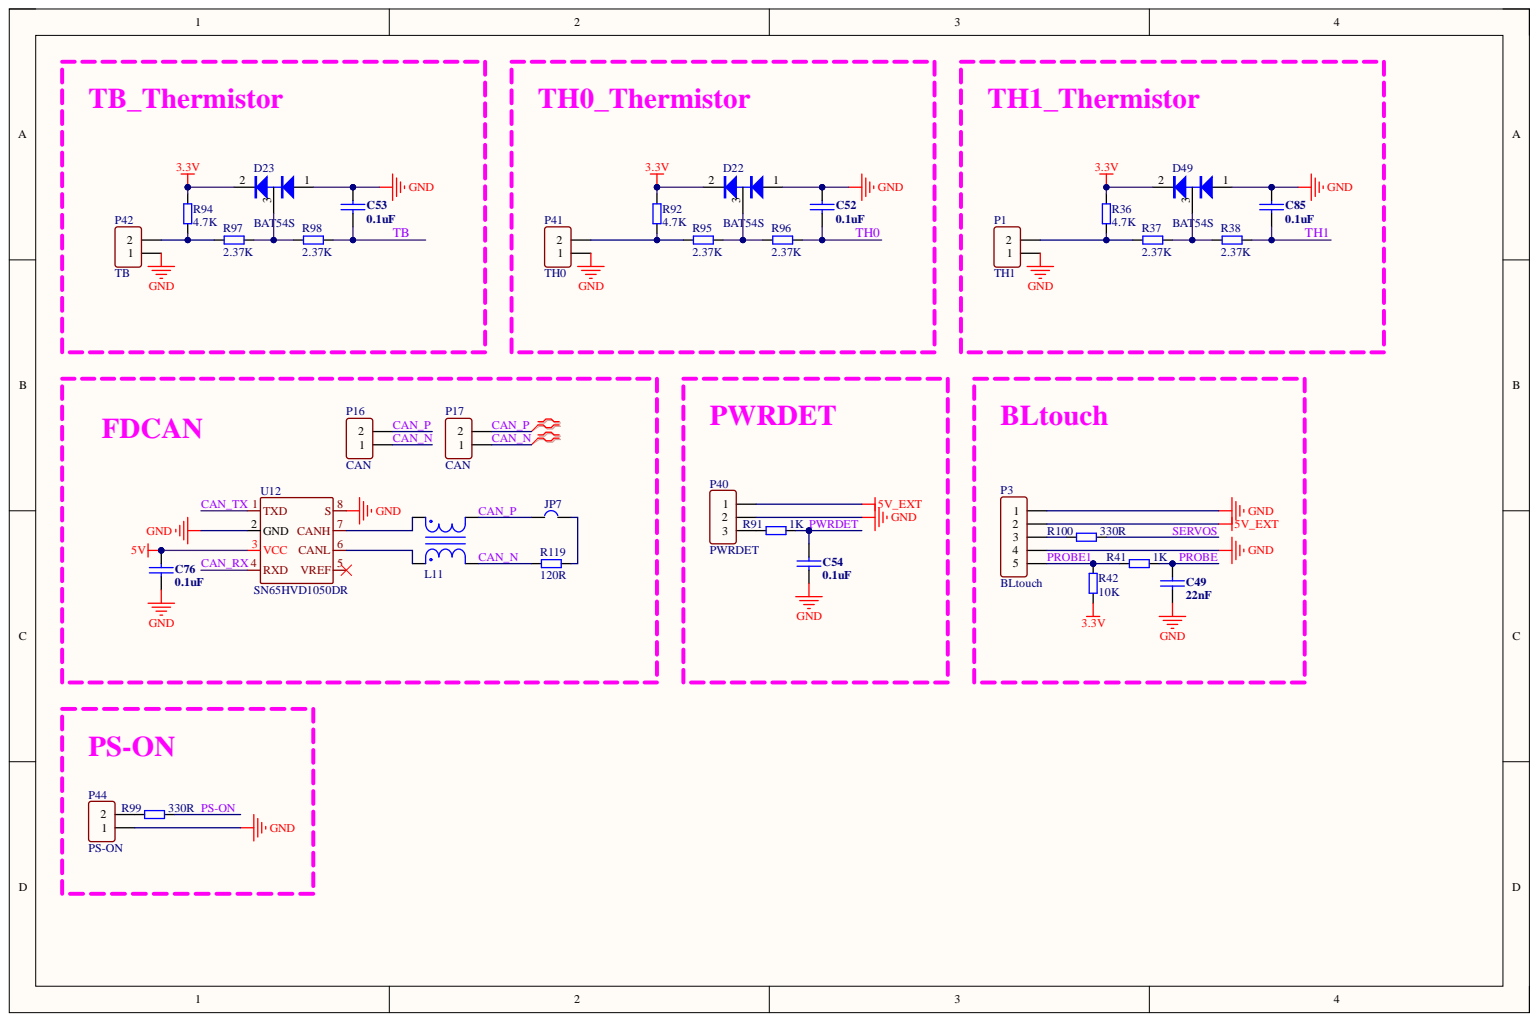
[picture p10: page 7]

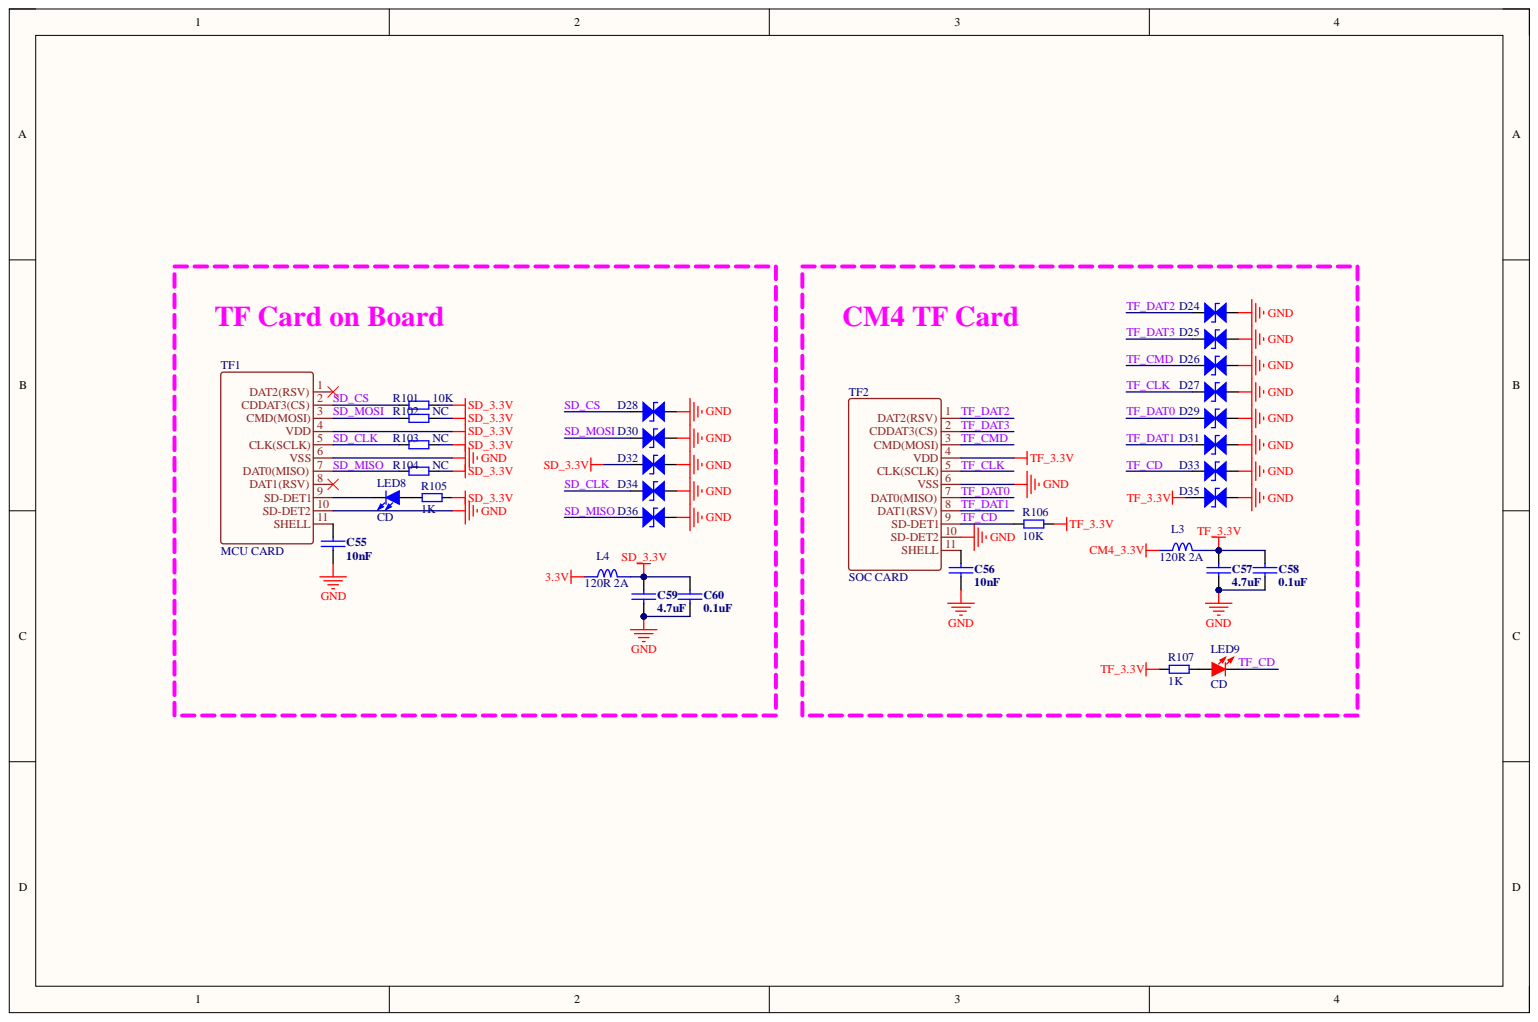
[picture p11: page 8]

TF Card on Board

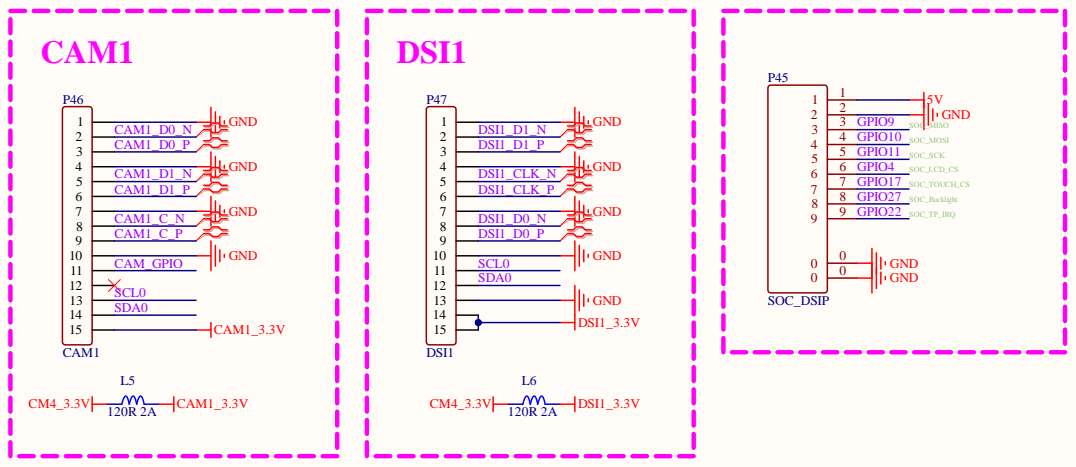
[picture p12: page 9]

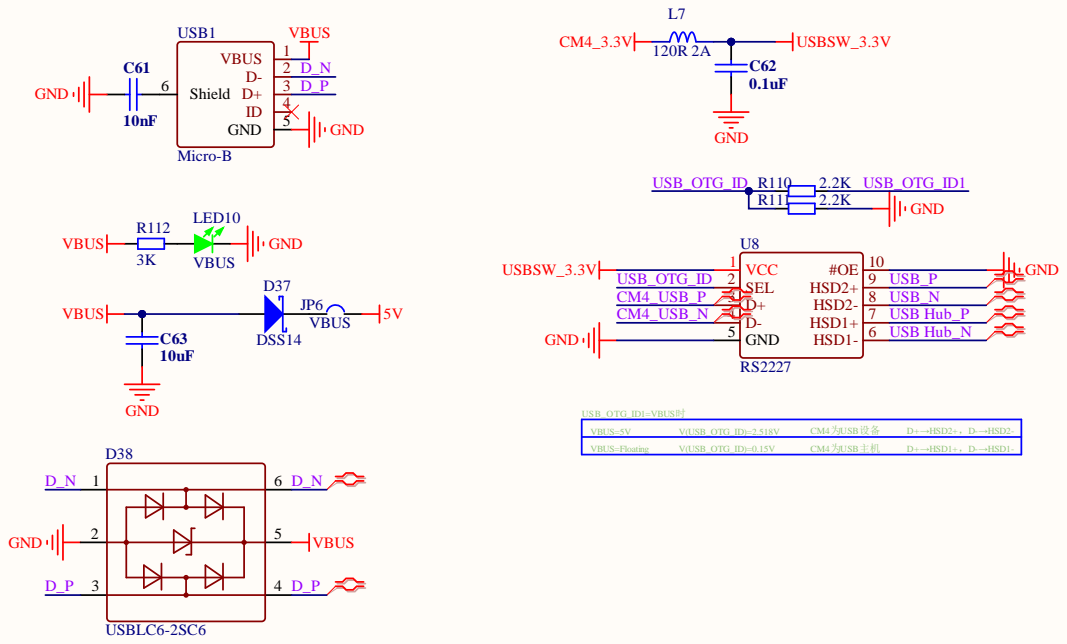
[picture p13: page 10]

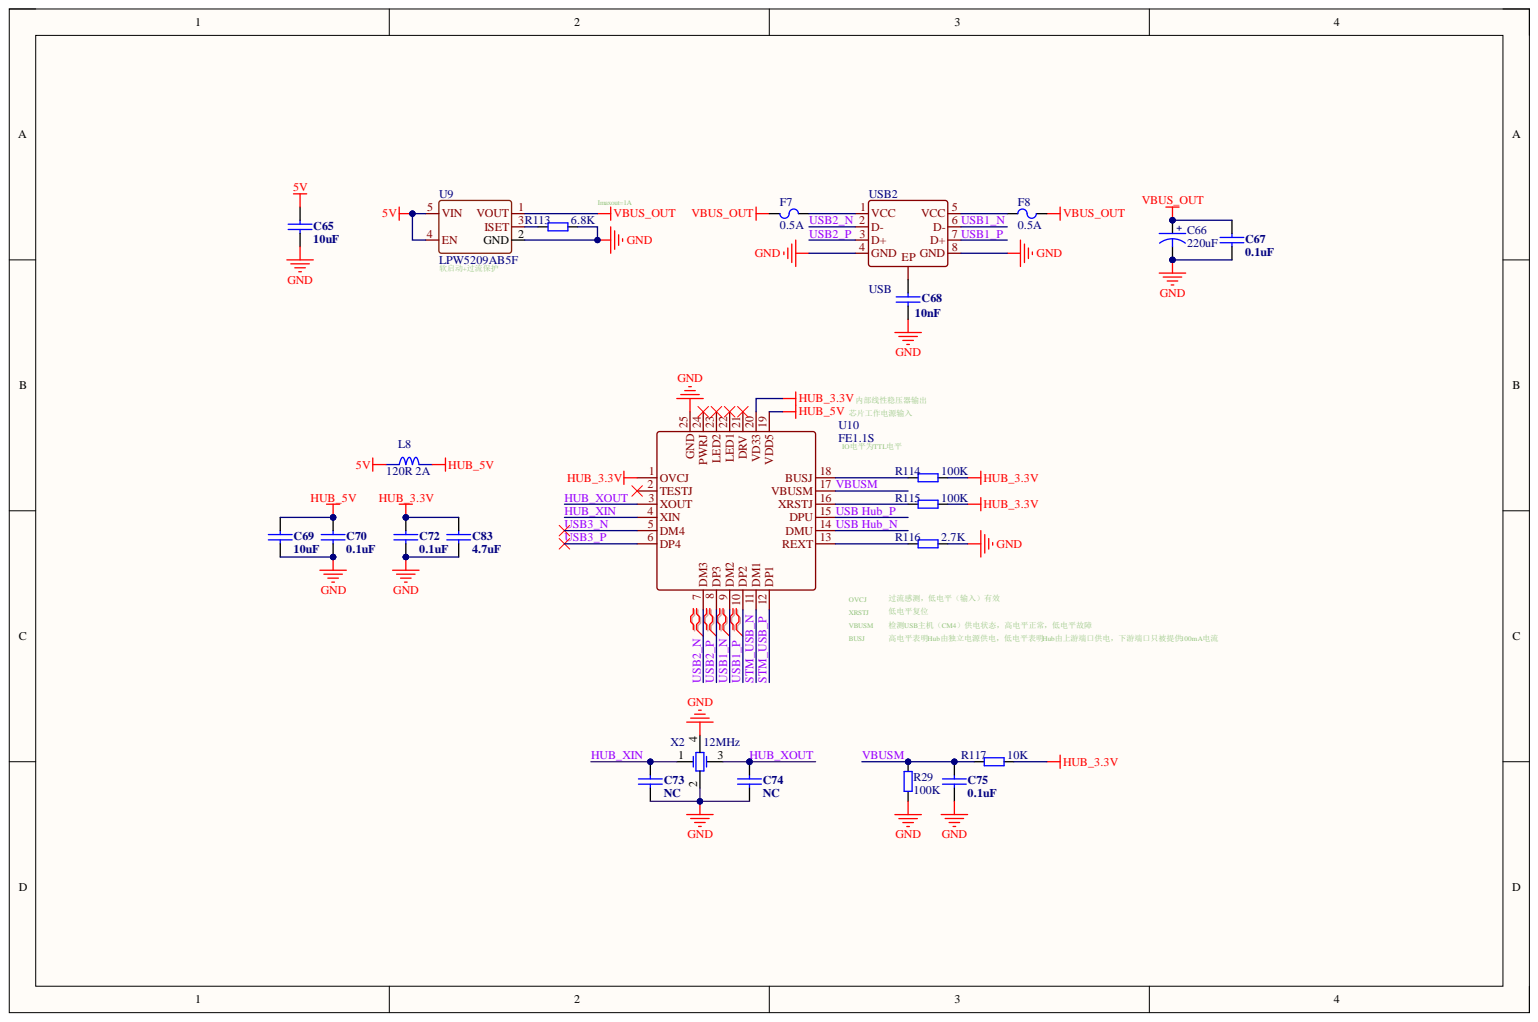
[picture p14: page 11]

REXT 13 DMU 14 DPU 15 XRSTJ 16 VBUSM 17 BUSJ 18 VDD5 19 VD33 20 DRV 21 LED1 22 LED2 23 PWRJ 24 GND 25

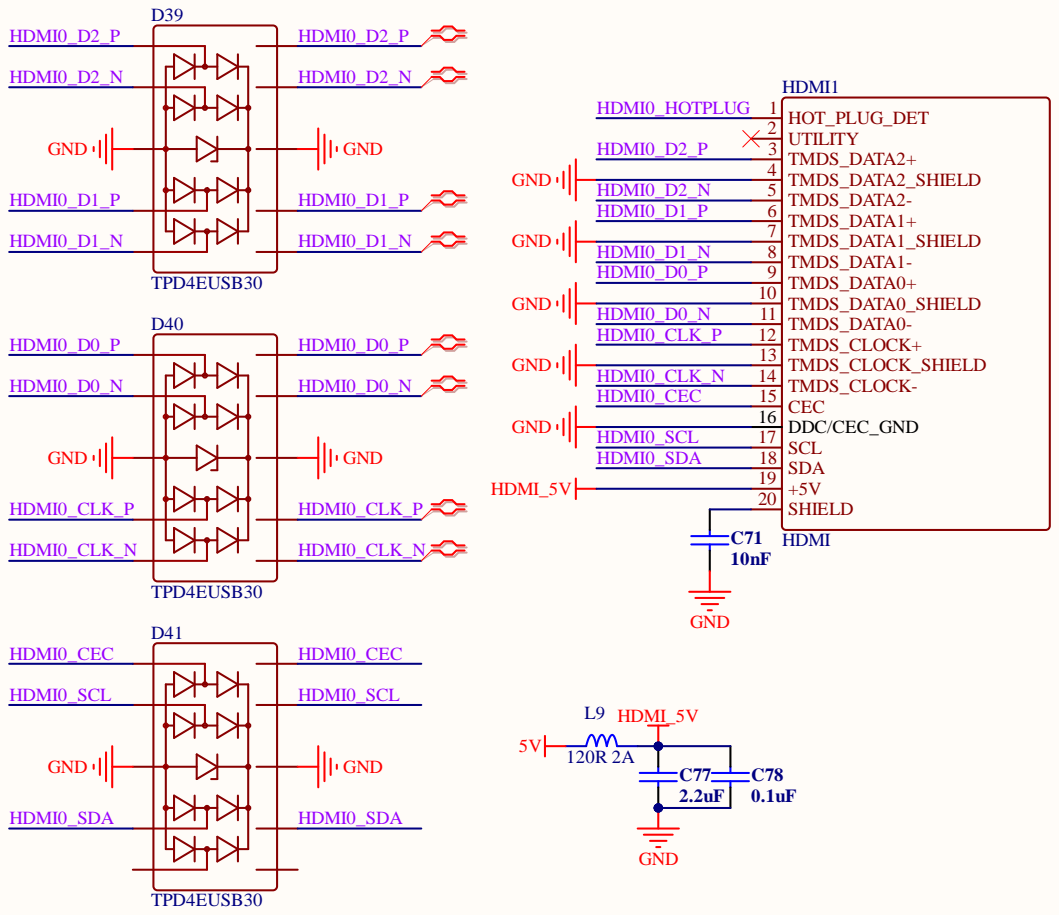
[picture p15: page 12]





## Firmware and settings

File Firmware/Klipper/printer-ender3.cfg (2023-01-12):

# This file contains common pin mappings for the BIGTREETECH Manta E3EZ
# To use this config, the firmware should be compiled for the
# STM32G0B1 with a "8KiB bootloader" "8 MHz crystal"
# and "USB (on PA11/PA12)" or "CAN bus (on PB12/PB13)".

# See docs/Config_Reference.md for a description of parameters.

[stepper_x]
step_pin: PA14
dir_pin: !PA10
enable_pin: !PA13
microsteps: 16
rotation_distance: 40
endstop_pin: ^PC4
position_endstop: 0
position_max: 235
homing_speed: 50

[stepper_y]
step_pin: PC8
dir_pin: !PA15
enable_pin: !PC14
microsteps: 16
rotation_distance: 40
endstop_pin: ^PB0
position_endstop: 0
position_max: 235
homing_speed: 50

[stepper_z]
step_pin: PD2
dir_pin: !PD4
enable_pin: !PD3
microsteps: 16
rotation_distance: 8
endstop_pin: ^PC6
position_endstop: 0
position_max: 270

[extruder]
step_pin: PD5
dir_pin: PD6
enable_pin: !PB3
microsteps: 16
rotation_distance: 33.500
nozzle_diameter: 0.400
filament_diameter: 1.750
heater_pin: PB11 #HE0
sensor_type: EPCOS 100K B57560G104F
sensor_pin: PA4 #TH0
control: pid
pid_Kp: 21.527
pid_Ki: 1.063
pid_Kd: 108.982
min_temp: 0
max_temp: 250

#[filament_switch_sensor material_0]
#switch_pin: PC5

#[extruder1]
#step_pin: PB7
#dir_pin: PB6
#enable_pin: !PB4
#heater_pin: PB10 # HE1
#sensor_pin: PA5 # T1

#[filament_switch_sensor material_1]
#switch_pin: PB1

[heater_bed]
heater_pin: PB2 #HB
sensor_type: EPCOS 100K B57560G104F #Generic 3950
sensor_pin: PA3 #TB
control: pid
# tuned for stock hardware with 50 degree Celsius target
pid_Kp: 54.027
pid_Ki: 0.770
pid_Kd: 948.182
min_temp: 0
max_temp: 130

[fan]
pin: PA8

#[heater_fan fan1]
#pin: PB15

#[heater_fan fan2]
#pin: PB14

[mcu]
serial: /dev/serial/by-id/usb-Klipper_Klipper_firmware_12345-if00

[printer]
kinematics: cartesian
max_velocity: 300
max_accel: 3000
max_z_velocity: 5
max_z_accel: 100

########################################
# TMC2209 configuration
########################################

#[tmc2209 stepper_x]
#uart_pin: PB8
##diag_pin: PC4
#run_current: 0.800
#stealthchop_threshold: 999999

#[tmc2209 stepper_y]
#uart_pin: PC9
##diag_pin: PB0
#run_current: 0.800
#stealthchop_threshold: 999999

#[tmc2209 stepper_z]
#uart_pin: PD0
##diag_pin: PC6
#run_current: 0.650
#stealthchop_threshold: 999999

#[tmc2209 extruder]
#uart_pin: PD1
#run_current: 0.800
#stealthchop_threshold: 999999

#[tmc2209 extruder1]
#uart_pin: PB5
#run_current: 0.800
#stealthchop_threshold: 999999

########################################
# TMC2130 configuration
########################################

#[tmc2130 stepper_x]
#cs_pin: PB8
#spi_software_miso_pin: PC11
#spi_software_mosi_pin: PC12
#spi_software_sclk_pin: PC10
##diag1_pin: PF3
#run_current: 0.800
#stealthchop_threshold: 999999

#[tmc2130 stepper_y]
#cs_pin: PC9
#spi_software_miso_pin: PC11
#spi_software_mosi_pin: PC12
#spi_software_sclk_pin: PC10
##diag1_pin: PF4
#run_current: 0.800
#stealthchop_threshold: 999999

#[tmc2130 stepper_z]
#cs_pin: PD0
#spi_software_miso_pin: PC11
#spi_software_mosi_pin: PC12
#spi_software_sclk_pin: PC10
##diag1_pin: PF5
#run_current: 0.650
#stealthchop_threshold: 999999

#[tmc2130 extruder]
#cs_pin: PD1
#spi_software_miso_pin: PC11
#spi_software_mosi_pin: PC12
#spi_software_sclk_pin: PC10
#run_current: 0.800
#stealthchop_threshold: 999999

#[tmc2130 extruder1]
#cs_pin: PB5
#spi_software_miso_pin: PC11
#spi_software_mosi_pin: PC12
#spi_software_sclk_pin: PC10
#run_current: 0.800
#stealthchop_threshold: 999999

[board_pins]
aliases:
    # EXP1 header
    EXP1_1=PC1, EXP1_3=PC3, EXP1_5=PC0, EXP1_7=PA2, EXP1_9=<GND>,
    EXP1_2=PC2,  EXP1_4=<RST>, EXP1_6=PA0, EXP1_8=PA1, EXP1_10=<5V>

#[bltouch]
#sensor_pin: PA6
#control_pin: PA7

#[output_pin PS_ON]
#pin: PA9

#[output_pin pb9_pin]
#pin: PB9

#[neopixel my_neopixel]
#pin: PC7

#[adxl345]
#cs_pin: PC15
#spi_software_miso_pin: PC11
#spi_software_mosi_pin: PC12
#spi_software_sclk_pin: PC10

[bed_screws]
screw1: 30.5, 37
screw2: 30.5, 207
screw3: 204.5, 207
screw4: 204.5, 37

[display]
lcd_type: st7920
cs_pin: EXP1_7
sclk_pin: EXP1_6
sid_pin: EXP1_8
encoder_pins: ^EXP1_5, ^EXP1_3
click_pin: ^!EXP1_2

[output_pin beeper]
pin: EXP1_1

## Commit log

2023-01-12 add E3EZ info
    [generic-bigtreetech-manta-e3ez.cfg]
2023-01-12 ender3 config
    [printer-ender3.cfg]
2023-01-30 Add the description of screw hole size of fixed core board
2023-02-06 add stls
    [Back enclosure.stl, Ender5.STL, Front enclosure.stl]
2023-04-04 update pins for canbus pin name
2023-04-20 120R for CANbus pinout
2024-12-24 Updated the board step
2025-03-27 manual: Raspberry Pi 2023-10-10 and later systems, the configuration path changes from '/boot/' to '/boot/firmware'
2025-10-09 Modify software SPI to hardware SPI
